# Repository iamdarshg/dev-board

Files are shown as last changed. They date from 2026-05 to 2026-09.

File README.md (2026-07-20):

# dev-real — what's left to do

Self-contained project: board + schematics + libraries. Unzip anywhere and open
`dev-real.kicad_pro` in KiCad 9.

Board is at **0 DRC errors and 0 unconnected items — fully routed.**

---

## 1. Routing complete (historical)

All 14 unconnected items from the previous pass (was 499 originally) have
been resolved, including the last 6 hold-outs around the U13 radar BGA
corner (GND ball M12, an In2/GND stub near (56.9, 16.0), C34 pad 1, U21 pad
26, a split GND plane island on In1, and an NRESET In1↔F gap) — these needed
hand-routing (via-in-pad style connections plus small shoves of a couple of
neighboring nets — FT_RXD, GPIO_4 — that were routed directly under the
affected pads) since the escape-track congestion in that corner defeats the
interactive shove router's default settings. `Inspect → Design Rules
Checker → Run DRC` now reports **0 errors, 0 unconnected** with zones
refilled.

If future edits reintroduce unconnected items, the same workflow applies:

1. Open `dev-real.kicad_pro` → PCB Editor.
2. `Route → Interactive Router Settings…` → set **Mode: Shove** (Walk Around
   struggles near the U13 BGA corner, where several nets route directly
   under neighboring balls).
3. `Inspect → Design Rules Checker → Run DRC`, open the **Unconnected
   Items** tab, double-click an item to zoom to it.
4. Hover the pad → press `X` → route → double-click to finish. Press `V`
   mid-route to drop a via and switch layers.
5. Press `B` to refill all zones before the final DRC check — stale zone
   fill after a track/via edit can itself show up as a false clearance
   violation until refilled.

## 2. Fix SCOPE_BIAS in the schematic

`/AD9609/SCOPE_BIAS` has **no DC reference** anywhere in the schematic — the net
floats on the real board. Open `ad9609bcpzrl7_80_breakout.kicad_sch` and define
the intended bias source, then `Tools → Update PCB from Schematic` (F8).

## 3. Sanity-check before you save

After any edit: press `B` to refill zones, then `Inspect → Design Rules
Checker → Run DRC` and confirm it still reads **0 errors, 0 unconnected**
before `Ctrl+S`.

---

### Design rules already in effect (don't change)

Signal 0.127 mm / vias 0.254 mm with 0.127 mm drill / clearance 0.08 mm /
min through-drill 0.127 mm. Power rails run 0.2–0.5 mm.
The 0.2/0.1 vias on this board are **microvias** — place a new *through*-via
that small and DRC will (correctly) reject it.

### What's in here

- `dev-real.kicad_pcb` — the board
- `dev-real.kicad_pro` — project + design rules (**keep beside the board**;
  without it KiCad invents default rules and DRC becomes meaningless)
- `dev-real.kicad_sch` + 8 hierarchical sheets — full schematic
- `fp-lib-table`, `sym-lib-table` + the custom symbol/footprint libraries they
  reference (AD9609, IWRL6432, MM8108, THS8136, XCC1352, ICM-42670, ENS161,
  MMC5633, plus the project's `.pretty` footprint dirs)

Verified standalone: netlist exports all 318 components across the 9-sheet
hierarchy, and DRC output is identical to the working copy.

Full history, method, DRC report, renders and the routing scripts stay in
`D:\dev-real-updated\dev-real-updated\dev-real-routing-finish\`.

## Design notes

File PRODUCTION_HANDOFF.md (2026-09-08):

# Production handoff

## Release artifacts

- PCB: `dev-real-production.kicad_pcb`
- KiCad project rules: `dev-real-production.kicad_pro`
- Fabrication archive: `dev-real-production-fab.zip`
- DRC report: `dev-real-production-drc.rpt`
- Detailed pair audit: `dev-real-production-length-audit.txt`

The current KiCad 9.0.7 DRC result is **26 warnings, 0 errors, 0 unconnected
items, and 0 footprint errors** after the 2026-09-09 dangling-copper cleanup
and full eight-zone refill. The remaining warnings are explicitly classified
in the current-routing section below.

**Fab outputs are stale as of the L1 change below.** `dev-real-production-fab/`
(gerbers, drill files, `-positions.csv`, `-netlist.xml`, `-drc.rpt`, `.zip`) and
`dev-real-production-length-audit.txt` were generated before L1 was replaced and
rerouted, and were intentionally **not** regenerated here (kicad-cli's default
export job doesn't reproduce this project's curated gerber/drill file set —
e.g. the PTH/NPTH split — without its saved plot-job settings). Before sending
to a fabricator: open `dev-real-production.kicad_pro` in KiCad 9 and re-run
**File → Fabrication Outputs** (or the project's existing plot job) to
regenerate the whole `dev-real-production-fab/` package and `.zip` from the
current board.

## L1 inductor (1 µH buck output, `/Power/SW` → `+3V3`)

L1 was a placeholder (`L_TODO_SELECT_1uH_15Aplus`, physically a 0603 footprint)
and is now **KYOCERA AVX LMLP07C7M1R0DTAS** (1 µH ±20 %, DCR 6.1/6.5 mΩ typ/max,
IDC 15 A typ, Isat 20 A typ) on footprint `L_Kyocera_LMLP07C7D_7.3x6.6mm`
(land pattern built from the LMLP07 series dimensional table in
`datasheets.kyocera-avx.com/LMLPD.pdf` — verify against that drawing before
committing to fab). COUT2 (the buck output cap, itself still a
`C_TODO_SELECT_100uF` placeholder) was nudged ~1.85 mm to make room, and the
~12 local nets crossing the new footprint's footprint were rerouted and
verified against real `kicad-cli pcb drc`.

**Fixed:** the `courtyards_overlap` between C5 and COUT2 noted above has been
resolved. COUT2 could not be moved (the channel between C5 and L1's new body
is too narrow for COUT2's footprint in any orientation, and COUT2's own
routing was already verified/stable), so C5 (100 nF, `C_0603_1608Metric`) was
relocated instead, from (68.5, 59.5) mm to (67.7, 57.75) mm — clear of both
COUT2's and C2's courtyards, with a real `kicad-cli pcb drc` clean pass
(0 violations / 0 unconnected). Its two local stub nets were rerouted to the
new pad positions on the Top Layer: `/Power/RIPPLE_INJ` (pad at
(66.925, 57.75)) reconnects with a single straight segment to its existing
run at (65.674999, 57.449999); `/Power/FB` (pad at (68.475, 57.75)) is
routed around an `/Power/EXTVDD` track that crosses the direct path, via
waypoints (68.6, 58.0) → (70.4, 58.0) → (70.8, 58.4) → (71.0, 58.4) →
(71.6, 59.0) → (71.0, 59.6) → (69.2, 59.6), rejoining the existing FB run at
(69.3, 59.524999). Six duplicate/redundant `/Power/FB` stub segments left
over from earlier routing passes (all at the same old coordinates) were
deduped down to the single new route in the process.

## High-current trace widths

The `/Power/SW` and `+3V3` segments added/touched by the L1 reroute were
widened from their as-routed 0.1–0.2 mm to 0.2–0.4 mm (clearance-checked
per segment, matching this board's existing convention for local
high-current power hops — see the `+3V3`/`/Power/SW` segments elsewhere on
the board already at 0.4 mm). A board-wide sweep of the other plausible
current-carrying nets (`/Power/VIN`, `/Power/SVIN`, `/Power/PVDD`,
`/Power/EXTVDD`, the USB VBUS nets) found them already consistent with this
convention (0.18–0.35 mm), with one exception: `/IWRL6432BD/USB_VBUS` had
~7.8 mm routed at only 0.15 mm across a few inner-layer segments. Five of
those segments have been widened to 0.2–0.3 mm. Two short segments — a
4.64 mm run on Power Layer 2 near (52.7–57.2, 27.1–28.0) and a 3.19 mm run
on Ground Layer 1 near (57.5–59.5, 28.3–30.7) — remain at 0.15 mm because a
neighboring `/Power/1V8` via sits close enough that widening them trips
real DRC clearance; widening those two needs either moving that via or
re-routing around it, left for interactive follow-up.

## ADC/DAC test breakout

The exposed 1.0 mm test pads are grouped on the bottom edge at 2.0 mm pitch:

| Reference | Net | Position (mm) |
|---|---|---:|
| TP8 | ADC VIN+ | 79, 11 |
| TP9 | ADC VIN- | 81, 11 |
| TP1 | DAC red / AR | 83, 11 |
| TP2 | DAC green / AG | 85, 11 |
| TP3 | DAC blue / AB | 87, 11 |

ADC test-branch mismatch is 0.509 mm. These are measurement branches; keep probes and flying leads short.

## Current routing status (2026-09-09; cleaned manual-routing candidate)

The checked-in board contains the latest manual KiCad routing plus a
conservative basic-DRC cleanup. The cleanup removed **59 zero-pad signal track
segments**, **20 zero-pad signal vias**, **5 byte-identical duplicate vias**,
and **12 exact F.SilkS primitives** named by DRC. The undersized `TR1` and `U6`
reference text was resized to 0.8 mm and moved clear. This eliminated every
`silk_over_copper`, `silk_overlap`, and `text_height` violation. A deliberately
broader cleanup was tested and rejected because it created a genuine
unconnected item; sensitive and ambiguous one-pad routes therefore remain for
visual review instead of being deleted automatically.

The 2026-09-09 follow-up then iteratively removed every newly exposed dead-end
chain that passed a fresh connectivity check: **90 additional dangling track
blocks and 27 additional dangling-via blocks** were removed. Nine more
redundant members of co-located via pairs were removed directly; combined with
the dangling-via removal, this cleared **18 of the 20** co-location markers.
All eight zones were refilled. The refill removed the two former physical
via-to-zone conflicts (four error records) without creating shorts or
unconnected items.

KiCad 9.0.7 DRC on the resulting board reports **26 warnings, 0 errors, 0
unconnected items, and 0 footprint errors**. The remaining warnings are:

- **One `track_dangling` marker:** `/STM32H7/JTDI` at approximately
  (21.5420, 40.3517) mm. A test deletion created a real missing connection, so
  that deletion was reverted and this marker is intentionally accepted.
- **Two `holes_co_located` markers:** the `/Power/SW` microvia-to-buried-via
  transitions at (71.5000, 66.0000) mm and (71.5000, 66.2000) mm. Removing a
  member created a missing connection. A tested stagger-and-bridge alternative
  cleared co-location but created four `/Power/SW` to `+3V3` shorts after zone
  refill, so it too was reverted. These are required stacked transitions and
  need fabricator approval rather than deletion.
- **Five `copper_sliver` markers:** two Top Layer, two Bottom Layer, and one
  Power Layer 2. KiCad's machine-readable report supplies no coordinates or
  attached objects for these markers. A complete eight-zone refill was clean
  electrically but did not remove the warnings, so they remain accepted for
  later interactive marker inspection rather than hiding them by lowering DRC
  severity.
- **Ten `hole_to_hole` warnings:** remaining HDI drill-spacing/stack geometry
  that must be accepted by the selected fabricator or manually restacked.
- **Eight `lib_footprint_mismatch` warnings:** `J7`, `U3`, `RANT1`, and
  `CANT1` reflect intentional local silkscreen cleanup; `NT1`, `U21`, `U14`,
  and `U15` were pre-existing. There are no footprint errors.

This remains a review candidate, not a fabrication release. The previously
released board at commit `3a95473` remains the clean fabrication baseline, and
the fabrication outputs listed above have not been regenerated.

The following are the remaining measured end-to-end pair mismatches on the
checked-in board. They are documented for interactive KiCad follow-up; they
must not be treated as solved merely because the board passes ordinary DRC:

| Interface | Measured mismatch | Status |
|---|---:|---|
| IWRL USB DM/DP to J10 | 0.097 mm | manually tuned; verify after DRC fix |
| RP2350 USB D-/D+ to J4 | 0.967 mm | manually tuned; verify after DRC fix |
| STM32 USB FS D-/D+ to J20 | 0.414 mm | manually tuned; verify after DRC fixes |
| AD9609 sample clock CLK-/CLK+ | 0.304 mm | manually tuned; verify after DRC fixes |
| Ethernet RX RX-/RX+ to J21 | 0.021 mm | manually tuned; verify after DRC fix |
| Ethernet TX TX-/TX+ | 0.000 mm | corrected and DRC-verified |
| MM8108 USB D-/D+ to J17 | 0.675 mm | manually tuned; verify after DRC fix |
| AD9609 ADC input | 0.581 mm | open; analog path review |

The IWRL connector is J10 (`USB-C USB2 DEBUG`); the RP2350 connector is J4
(`USB-C Receptacle USB2`). The STM32 USB connector is J20, and the MM8108
USB connector is J17. The current edited-board values above supersede the
older clean-board values in the historical audit below. The basic cleanup was
limited to zero-pad islands, exact duplicates, and silkscreen; it did not
intentionally tune these endpoint paths. They are not release values until DRC
is clean again.

The first-order field-based impedance estimate used the checked-in four-layer
stackup (1.6 mm nominal, 175 um prepreg to the adjacent reference plane,
FR-4 dielectric approximately 4.4) and the actual routed widths. It estimates
roughly 65--70 ohm single-ended and 89--96 ohm differential for the common
0.127--0.300 mm geometries. This is an engineering estimate, not a fab
acceptance measurement: the fabricator must field-solve the final stackup,
copper thickness, soldermask, and trace spacing and provide a coupon or
controlled-impedance confirmation. The short CC1352 RF balanced launches are
length-matched, but their 50 ohm launch impedance has not been certified by a
3-D field solver.

## Historical clean-board pair-length audit

Key routed mismatches:

| Pair | End-to-end mismatch |
|---|---:|
| ADC analog input | 0.072 mm |
| ADC sample clock | 0.572 mm |
| Ethernet RX | 0.260 mm |
| Ethernet TX | 3.723 mm |
| STM32 USB FS | 5.049 mm |
| MM8108 USB | 7.819 mm |
| RP2350 USB | 9.702 mm |
| FTDI USB | 16.235 mm |

The dense USB routes were not given forced serpentine sections because no collision-free tuning corridor was available. The STM32, RP2350, and FTDI paths are identified as full-speed USB in this design and are retained as routed. Confirm the MM8108 interface speed before fabrication: if it operates at USB high speed, its 7.819 mm residual mismatch should be rerouted against the module's timing requirement.

The historical Ethernet TX value in the table above predates the committed
correction. Use the 0.000 mm value in the current-routing section for the
checked-in production board.

## Fabricator instructions

- Four copper layers, nominal finished thickness 1.6 mm.
- The board contains F.Cu-to-In1.Cu laser microvias and In1.Cu-to-In2.Cu buried vias. Use an HDI process capable of the separated drill sets supplied in the archive.
- Confirm the smallest finished drill, annular ring, stacked-via policy, via filling/capping, soldermask expansion, and copper-to-edge limits against the KiCad board before accepting the order.
- Differential impedance must be field-solved by the selected fabricator using its actual laminate and plating data. Do not treat the nominal KiCad geometry as an impedance coupon.
- The project says only `Lead-Free` for copper finish; select the required finish explicitly on the fabrication purchase order.

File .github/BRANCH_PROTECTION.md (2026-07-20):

# Protecting the `main` branch

The `KiCad checks` workflow (`.github/workflows/kicad-checks.yml`) runs the KiCad 9
CLI on every pull request into `main` and fails if the production board
(`dev-real-production.kicad_pcb`) is not DRC-clean (0 violations, 0 unconnected).

CI only *reports* status. To actually **block merges** when it fails, `main` must
require that check. GitHub branch-protection settings are not part of the repo
files, so apply one of the following once (repo admin required).

## Required status check context
Use the job's display name exactly:

```
DRC — dev-real-production (required)
```

## Option A — GitHub UI
Settings → Branches → Add branch ruleset (or "Add rule") for `main`:
- Require a pull request before merging (≥ 1 approval recommended).
- Require status checks to pass before merging → add **DRC — dev-real-production (required)**.
- Require branches to be up to date before merging.
- Do not allow force pushes; do not allow deletions.

## Option B — `gh` CLI (REST)
```sh
gh api -X PUT repos/iamdarshg/dev-board/branches/main/protection \
  -H "Accept: application/vnd.github+json" \
  -f 'required_status_checks[strict]=true' \
  -f 'required_status_checks[contexts][]=DRC — dev-real-production (required)' \
  -f 'enforce_admins=true' \
  -f 'required_pull_request_reviews[required_approving_review_count]=1' \
  -f 'restrictions=' \
  -F 'allow_force_pushes=false' \
  -F 'allow_deletions=false'
```
(`restrictions` must be sent as null; with `gh api` an empty `-f 'restrictions='`
sends null. If your `gh` version rejects it, use the raw curl form below.)

## Option C — raw REST (curl)
```sh
curl -X PUT \
  -H "Authorization: Bearer $GITHUB_TOKEN" \
  -H "Accept: application/vnd.github+json" \
  https://api.github.com/repos/iamdarshg/dev-board/branches/main/protection \
  -d '{
    "required_status_checks": {
      "strict": true,
      "contexts": ["DRC — dev-real-production (required)"]
    },
    "enforce_admins": true,
    "required_pull_request_reviews": { "required_approving_review_count": 1 },
    "restrictions": null,
    "allow_force_pushes": false,
    "allow_deletions": false
  }'
```

Once the check has run at least once on a PR, its context becomes selectable in the
UI. After enabling, a PR that breaks production DRC cannot be merged into `main`.

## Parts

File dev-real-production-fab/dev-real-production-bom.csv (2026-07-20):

Refs | Value | Footprint | Qty | DNP
C1 | 4.7uF / >=10V | Capacitor_SMD:C_0805_2012Metric | 1
C2 | 2.2uF / >=10V | Capacitor_SMD:C_0603_1608Metric | 1
C3,C5,C65,C69,C70,C75,C98,C99,C102,C106,C107,C109,C110,C112-C116,C119-C126,C129,C130,C134 | 100nF | Capacitor_SMD:C_0603_1608Metric | 29
C4,C135 | 4.7nF | Capacitor_SMD:C_0603_1608Metric | 2
C6,C7 | 15pF C0G | RP2350B_minimal_hier:C_0402_1005Metric | 2
C8-C10 | 4.7uF 6.3V X5R | RP2350B_minimal_hier:C_0402_1005Metric | 3
C11,C12,C14,C16,C17,C20,C34,C35,C45 | 0.1uF | Capacitor_SMD:C_0402_1005Metric | 9
C13,C15,C18 | 22uF | Capacitor_SMD:C_0603_1608Metric | 3
C19,C26,C27,C37,C40,C49,C54,C61 | 1uF | Capacitor_SMD:C_0402_1005Metric | 8
C21-C23 | 100pF | Capacitor_SMD:C_0201_0603Metric | 3
C24,C25 | 4.7pF | Capacitor_SMD:C_0402_1005Metric | 2
C28,C39 | 0.22uF | Capacitor_SMD:C_0402_1005Metric | 2
C29,C30 | 22pF | Capacitor_SMD:C_0402_1005Metric | 2
C31,C33,C41-C43 | 2.2uF | Capacitor_SMD:C_0402_1005Metric | 5
C32 | 0.047uF | Capacitor_SMD:C_0402_1005Metric | 1
C36,C38,C44,C46,C47 | 10uF | Capacitor_SMD:C_0402_1005Metric | 5
C48 | 4.7uF | Capacitor_SMD:C_0402_1005Metric | 1
C50,C52,C53,C60,C71,C76,C77,C83 | 10uF | Capacitor_SMD:C_0603_1608Metric | 8
C51,C55-C59,C62,C63 | 100nF | Capacitor_SMD:C_0402_1005Metric | 8
C64,C67,C74 | 10uF | Capacitor_SMD:C_0805_2012Metric | 3
C66 | 22uF | Capacitor_SMD:C_0805_2012Metric | 1
C68,C78,C84,C89,C103,C118,C131,C132 | 1uF | Capacitor_SMD:C_0603_1608Metric | 8
C72,C79,C81,C85-C88,C92,C93 | 100n | Capacitor_SMD:C_0603_1608Metric | 9
C73 | 100nF BIAS | Capacitor_SMD:C_0603_1608Metric | 1
C80 | 100nF AVDD | Capacitor_SMD:C_0603_1608Metric | 1
C82 | 100nF DVDD | Capacitor_SMD:C_0603_1608Metric | 1
C90 | 100nF VDD | Capacitor_SMD:C_0603_1608Metric | 1
C91 | 100nF VOCM | Capacitor_SMD:C_0603_1608Metric | 1
C94 | 1nF VDD HF | Capacitor_SMD:C_0402_1005Metric | 1
C95 | 22pF C0G | Capacitor_SMD:C_0402_1005Metric | 1
C96,C101 | 12pF | Capacitor_SMD:C_0603_1608Metric | 2
C97,C105,C111 | 2.2uF low-ESR | Capacitor_SMD:C_0603_1608Metric | 3
C100,C104 | 4.7uF | Capacitor_SMD:C_0603_1608Metric | 2
C108,C117 | 6.8pF | Capacitor_SMD:C_0603_1608Metric | 2
C127,C128 | 18pF | Capacitor_SMD:C_0603_1608Metric | 2
C133 | 2.2uF | Capacitor_SMD:C_0603_1608Metric | 1
CIN1 | 10uF / >=10V | Capacitor_SMD:C_1210_3225Metric | 1
CIN2 | 39uF / >=10V | Capacitor_SMD:C_1210_3225Metric | 1
COUT1 | 47uF / >=6.3V | Capacitor_SMD:C_1210_3225Metric | 1
COUT2 | 100uF / >=6.3V | Capacitor_SMD:C_TODO_SELECT_100uF | 1
CSS1 | 12nF | Capacitor_SMD:C_0603_1608Metric | 1
CSVIN1 | 1uF / >=10V | Capacitor_SMD:C_0805_2012Metric | 1
C_ADC1,C_DVDD1-C_DVDD3,C_IOVDD1-C_IOVDD8,C_QSPI1,C_USB1,C_USB2,C_USBOTP1 | 100nF | RP2350B_minimal_hier:C_0402_1005Metric | 16
C_IOBULK1 | 10uF | RP2350B_minimal_hier:C_0402_1005Metric | 1
FB1,FB2,FB4-FB6 | 600R@100MHz | Inductor_SMD:L_0603_1608Metric | 5
FB3 | 600R@100MHz | Inductor_SMD:L_0805_2012Metric | 1
FB7-FB9 | 600R@100MHz | Inductor_SMD:L_0603_1608Metric_Pad0.95x0.95mm_HandSolder | 3
IC1 | ICM-42670-P | ICM-42670-P:ICM42670P | 1
IC2 | ENS161-BLGT_LGA9_T&R_1k5 | ENS161-BLGT_LGA9_T&R_1k5:ENS161BLGTLGA9TR1k5 | 1
J1 | VIN_IN | TerminalBlock_Phoenix:TerminalBlock_Phoenix_MKDS-1,5-2_1x02_P5.00mm_Horizontal | 1
J2 | TP_EN_PG | TerminalBlock_Phoenix:TerminalBlock_Phoenix_MKDS-1,5-2_1x02_P5.00mm_Horizontal | 1
J3 | TP_SW_FB | TerminalBlock_Phoenix:TerminalBlock_Phoenix_MKDS-1,5-2_1x02_P5.00mm_Horizontal | 1
J4,J17 | USB-C Receptacle USB2 | Connector_USB:USB_C_Receptacle_GCT_USB4105-xx-A_16P_TopMnt_Horizontal | 2
J5 | Conn_01x03_Pin | Connector_PinSocket_2.54mm:PinSocket_1x03_P2.54mm_Vertical | 1
J6 | ARM_Cortex_Debug_10 | Connector_PinHeader_1.27mm:PinHeader_2x05_P1.27mm_Vertical | 1
J7 | SMA_ANT_50OHM | Connector_Coaxial:SMA_Molex_73251-2120_EdgeMount_Horizontal | 1
J8 | 3V3_IN | Connector_PinHeader_2.54mm:PinHeader_1x02_P2.54mm_Vertical | 1
J10 | USB-C USB2 DEBUG | Connector_USB:USB_C_Receptacle_GCT_USB4105-xx-A_16P_TopMnt_Horizontal | 1
J11,J16 | ARM_JTAG_10 | Connector_PinHeader_1.27mm:PinHeader_2x05_P1.27mm_Vertical | 2
J12 | SOP0_SELECT | Connector_PinHeader_2.54mm:PinHeader_1x03_P2.54mm_Vertical | 1
J13 | SOP1_SELECT | Connector_PinHeader_2.54mm:PinHeader_1x03_P2.54mm_Vertical | 1
J14,J15 | Conn_01x03 | Connector_PinHeader_2.54mm:PinHeader_1x03_P2.54mm_Vertical | 2
J18 | Conn_01x03_Pin | Connector_PinHeader_2.54mm:PinHeader_1x03_P2.54mm_Vertical | 1
J19 | Cortex SWD/JTAG | Connector_PinHeader_1.27mm:PinHeader_2x05_P1.27mm_Vertical | 1
J20 | USB-C USB2 DEVICE | Connector_USB:USB_C_Receptacle_GCT_USB4105-xx-A_16P_TopMnt_Horizontal | 1
J21 | HR911105A MAGJACK | Connector_RJ:RJ45_Hanrun_HR911105A | 1
J22 | Conn_02x10_Counter_Clockwise | Connector_PinHeader_2.54mm:PinHeader_2x10_P2.54mm_Vertical | 1
J23 | Conn_02x04_Odd_Even | Connector_PinHeader_2.54mm:PinHeader_2x04_P2.54mm_Vertical | 1
L1 | 1uH LMLP07C7M1R0DTAS, Idc 15A / Isat 20A | Inductor_SMD:L_Kyocera_LMLP07C7D_7.3x6.6mm | 1
L2 | 3.3uH Abracon AOTA-B201610S3R3-101-T | RP2350B_minimal_hier:L_Abracon_AOTA-B201610S_2.0x1.6mm | 1
NT1 | AGND_to_PGND_single_point | NetTie:NetTie-2_SMD_Pad0.5mm | 1
R1,R35,R43,R46-R49,R62,REN1 | 100k | Resistor_SMD:R_0603_1608Metric | 9
R2 | 60.4k | Resistor_SMD:R_0603_1608Metric | 1
R3,R4 | 2R | Resistor_SMD:R_0603_1608Metric | 2
R5 | 24.3k | Resistor_SMD:R_0603_1608Metric | 1
R6,R70,R71 | 1k | RP2350B_minimal_hier:R_0402_1005Metric | 3
R7,R8,R28,R29 | 27R | RP2350B_minimal_hier:R_0402_1005Metric | 4
R9 | 33R 1% | RP2350B_minimal_hier:R_0402_1005Metric | 1
R10 | 100k | Resistor_SMD:R_0402_1005Metric | 1
R11,R12 | 10k | Resistor_SMD:R_0402_1005Metric | 2
R13,R14 | 27 | Resistor_SMD:R_0402_1005Metric | 2
R15,R16 | 0 | Resistor_SMD:R_0402_1005Metric | 2
R17 | 47.5k | Resistor_SMD:R_0402_1005Metric | 1
R18,R19 | 2M | Resistor_SMD:R_0402_1005Metric | 2
R20-R22 | 75R | Resistor_SMD:R_0402_1005Metric | 3
R23-R25,R27 | 2.2k | Resistor_SMD:R_0603_1608Metric | 4
R26 | 3.8k | Resistor_SMD:R_0402_1005Metric | 1
R30-R34 | 47k | Resistor_SMD:R_0603_1608Metric | 5
R36,R37,R39,R40 | 1k 0.1% | Resistor_SMD:R_0402_1005Metric | 4
R38 | 10k 1% | Resistor_SMD:R_0603_1608Metric | 1
R41,R42 | 33R | Resistor_SMD:R_0402_1005Metric | 2
R44,R50 | 0R | Resistor_SMD:R_0603_1608Metric | 2
R45,R65 | 1M | Resistor_SMD:R_0603_1608Metric | 2
R51-R55,R57,RPG1 | 10k | Resistor_SMD:R_0603_1608Metric | 7
R56 | 1.5k | Resistor_SMD:R_0603_1608Metric | 1
R58,R59 | 22R | Resistor_SMD:R_0603_1608Metric | 2
R60 | 100R | Resistor_SMD:R_0603_1608Metric | 1
R61 | 12.1k 1% | Resistor_SMD:R_0603_1608Metric | 1
R63,R64 | 5.1k | Resistor_SMD:R_0603_1608Metric | 2
R66,R67 | 330R | Resistor_SMD:R_0603_1608Metric | 2
R68,R69 | 10k STRAP LOW | Resistor_SMD:R_0603_1608Metric | 2
RANT1 | 0R | Resistor_SMD:R_0402_1005Metric | 1
RBOT1 | 665R | Resistor_SMD:R_0603_1608Metric | 1
RCC1-RCC4 | 5.1k | RP2350B_minimal_hier:R_0402_1005Metric | 4
RCL1 | 2.21k | Resistor_SMD:R_0603_1608Metric | 1
RTOP1 | 3.00k | Resistor_SMD:R_0603_1608Metric | 1
TP1 | AR_TP | TestPoint:TestPoint_Pad_D1.0mm | 1
TP2 | AG_TP | TestPoint:TestPoint_Pad_D1.0mm | 1
TP3 | AB_TP | TestPoint:TestPoint_Pad_D1.0mm | 1
TP4,TP5 | VCM | TestPoint:TestPoint_Pad_D1.0mm | 2
TP6 | VREF | TestPoint:TestPoint_Pad_D1.0mm | 1
TP7 | AVDD_1V8 | TestPoint:TestPoint_Pad_D1.0mm | 1
TP8 | ADC_VIN_P | TestPoint:TestPoint_Pad_D1.0mm | 1
TP9 | ADC_VIN_N | TestPoint:TestPoint_Pad_D1.0mm | 1
TR1 | 0900PC15A0036 | XCC1352R1F3RGZR_RF:Johanson_0900PC15A0036_0805_10Pin | 1
U1 | MMC5633NJL | Package_BGA:WLP-4_0.86x0.86mm_P0.4mm | 1
U2 | LPS22HH | Package_LGA:ST_HLGA-10_2x2mm_P0.5mm_LayoutBorder3x2y | 1
U3 | MIC28516T-E/PHA | MIC28516:MIC28516-VQFN-32-6x6mm-P0.65-MultipleEP | 1
U4 | RP2350B | RP2350B_minimal_hier:RP2350B_QFN80_10x10mm_P0.4mm_EP | 1
U5 | XCC1352R1F3RGZR | Package_DFN_QFN:VQFN-48-1EP_7x7mm_P0.5mm_EP5.15x5.15mm | 1
U6 | XMSSJJ3G0PA-054 | XCC1352R1F3RGZR_RF:Murata_XMSSJJ3G0PA-054 | 1
U7 | TLV75518PDBV | Package_TO_SOT_SMD:SOT-23-5 | 1
U8 | TLV75518PDBVR | Package_TO_SOT_SMD:SOT-23-5 | 1
U9,U10 | USBLC6-2P6 | Package_TO_SOT_SMD:SOT-666 | 2
U11,U12 | FT230XS-R | Package_SO:SSOP-16_3.9x4.9mm_P0.635mm | 2
U13 | IWRL6432BDBAAMFR | iwrl6432_custom:IWRL6432_AMF_FCCSP-102_6.45x6.45mm_P0.50mm | 1
U14,U15 | MX25R1635FZUIH0 | Package_SON:WSON-8-1EP_6x5mm_P1.27mm_EP3.4x4mm | 2
U16 | AMS1117-1.8 | Package_TO_SOT_SMD:SOT-223-3_TabPin2 | 1
U17 | THS8136 | THS8136IPHPR:QFP50P900X900X120-49N | 1
U18 | MM8108-MF15457 | MM8108-MF15457:MM8108MF15457 | 1
U19 | AP2112K-1.8 | Package_TO_SOT_SMD:SOT-23-5 | 1
U20 | PGA113AIDGSR | Package_SO:VSSOP-10_3x3mm_P0.5mm | 1
U21 | AD9609BCPZRL7-80 | Package_DFN_QFN:QFN-32-1EP_5x5mm_P0.5mm_EP3.45x3.45mm_ThermalVias | 1
U22 | MCP6D11T-E/MS | Package_SO:MSOP-8_3x3mm_P0.65mm | 1
U23 | STM32H7S3Z8T6 | Package_QFP:LQFP-144_20x20mm_P0.5mm | 1
U24 | LAN8742A-CZ-TR | Package_DFN_QFN:QFN-24-1EP_4x4mm_P0.5mm_EP2.6x2.6mm | 1
U25 | USBLC6-2SC6 | Package_TO_SOT_SMD:SOT-23-6 | 1
Y1 | 12MHz ABM8-272-T3 | RP2350B_minimal_hier:Crystal_ABM8_3.2x2.5mm | 1
Y2 | 48MHz | Crystal:Crystal_SMD_3225-2Pin_3.2x2.5mm | 1
Y3 | 40MHz | Crystal:Crystal_SMD_3225-2Pin_3.2x2.5mm | 1
Y4 | 40MHz | Crystal:Crystal_SMD_3225-4Pin_3.2x2.5mm | 1
Y5 | 24MHz | Crystal:Crystal_SMD_3225-4Pin_3.2x2.5mm | 1
Y6 | 32.768kHz | Crystal:Crystal_SMD_3215-2Pin_3.2x1.5mm | 1
Y7 | 25MHz | Crystal:Crystal_SMD_3225-4Pin_3.2x2.5mm | 1

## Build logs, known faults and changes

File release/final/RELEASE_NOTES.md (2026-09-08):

# dev-board Fabrication Release Notes

Revision: main @ (see SHA256SUMS.csv for exact source hashes)
Generated: 2026-09-08 (Asia/Calcutta)
Generator: KiCad 9.0.7 CLI

## Contents

- dev-real-gerbers/ — Gerbers (F.Cu, In1, In2, B.Cu, masks, pastes, silkscreens, Edge.Cuts) + Excellon drills (PTH + 3 blind/buried lamination pairs) + drill maps (PDF) for dev-real.kicad_pcb
- dev-real-production-gerbers/ — Same set for dev-real-production.kicad_pcb
- dev-real-bom.csv / dev-real-production-bom.csv — Bill of Materials
- dev-real-positions.csv / dev-real-production-positions.csv — Pick-and-place positions
- dev-real-schematic.pdf — Full hierarchical schematic (9 sheets)
- erc-report.rpt — Full-hierarchy ERC report
- drc-dev-real.rpt / drc-dev-real-production.rpt — DRC reports with schematic parity

## Verification results

| Check | dev-real | dev-real-production |
|---|---|---|
| DRC errors | 0 | 0 |
| DRC unconnected items | 0 | 0 |
| ERC errors | 88 | (same schematic) |
| ERC warnings | 840 | (same schematic) |
| Board size | 105 x 105 mm | 105 x 105 mm |
| Layers | 4 (F.Cu/In1-GND/In2-PWR/B.Cu), 1.6 mm | same |

ERC error classification: all remaining ERC errors are deliberate design conditions or
library-symbol consistency warnings — no actual electrical faults found:
- power_pin_not_driven (32): power-input pins driven through hierarchical sheet boundaries;
  KiCad''s ERC cannot see the driving source across sheets.
- label_dangling (25): root-sheet hierarchical labels for optional/debug interfaces left unwired by design.
- pin_not_connected (7): deliberately unused RESV/NC pins on IC1, J6 pin 7, U5 DIO_7.
- hier_label_mismatch (9): hierarchical labels present in child sheets but intentionally not broken out to parent.
- pin_to_pin (1): VDDA_10RF output-output tie on U13 (IWRL6432) per TI reference design.

## Known accepted issue: /AD9609/SCOPE_BIAS

The net /AD9609/SCOPE_BIAS connects only R36 pin 2 and C73 pin 2 (C73''s other side is GND).
R36''s other end ties to the MCP6D11 differential driver''s IN- summing node. The net has no DC source —
it is electrically floating on the assembled board. Determining the intended bias voltage (GND vs VCM vs VREF,
given the PGA113 output operating point and VOCM setting) would require inventing analogue design intent that
is not documented anywhere in the project. Per explicit user decision this issue is accepted as-is and left
unresolved. It affects only the AD9609 scope-driver subcircuit (U22 MCP6D11 input bias reference).

No other nets are unresolved. Both PCB variants have identical SCOPE_BIAS connectivity (2 pads each).

## Current routing and signal-integrity status

The checked-in production board is the board at commit `3a95473`. After the
Ethernet TX correction, KiCad 9.0.7 DRC reports **0 errors** and **0
unconnected items**. The `/STM32H7/PHY_TXP` and `/STM32H7/PHY_TXN` pair is
length-matched to **0.000 mm**.

Measured end-to-end mismatches still open for interactive KiCad tuning are:

| Interface | Mismatch |
|---|---:|
| IWRL USB DM/DP | 21.981 mm |
| RP2350 USB D-/D+ | 5.925 mm |
| STM32 USB FS D-/D+ | 2.196 mm |
| AD9609 sample clock CLK-/CLK+ | 2.100 mm |

These are not DRC errors. The dense USB/radar corridors need visual review and
length tuning with serpentine sections only where clearance and return-path
continuity remain intact. The first-order field-based estimate for the
checked-in four-layer stackup is approximately 65--70 ohm single-ended and
89--96 ohm differential for the common routed widths. It is an estimate, not
a controlled-impedance release: the selected fabricator must field-solve the
actual laminate/plating/soldermask stackup and confirm the target geometry
with a coupon or equivalent measurement. The CC1352 RF launches are
length-matched, but no 3-D field-solver certification has been performed.

The release is therefore electrically DRC-clean and fabrication-packaged,
with Ethernet TX corrected, but it is not claiming completed impedance
certification or completion of the remaining manual skew-tuning work.

## Manufacturing notes

- HDI build: microvias and blind/buried via pairs (front-In1, front-In2, In1-In2 laminations) require
  sequential-lamination capability; not a standard low-cost through-via process.
- Design rules: min track 0.127 mm, min via 0.254 mm/0.127 drill, microvia 0.2 mm/0.1 drill, clearance 0.08 mm.
- Drill files use absolute origin, millimetre units, Excellon format. Layer-specific drill files are provided
  for the blind/buried pairs plus a combined PTH file.
- Board outline: closed rectangle, Edge.Cuts layer, 105 x 105 mm.
- Zones refilled at time of export; filled polygons present on both boards.

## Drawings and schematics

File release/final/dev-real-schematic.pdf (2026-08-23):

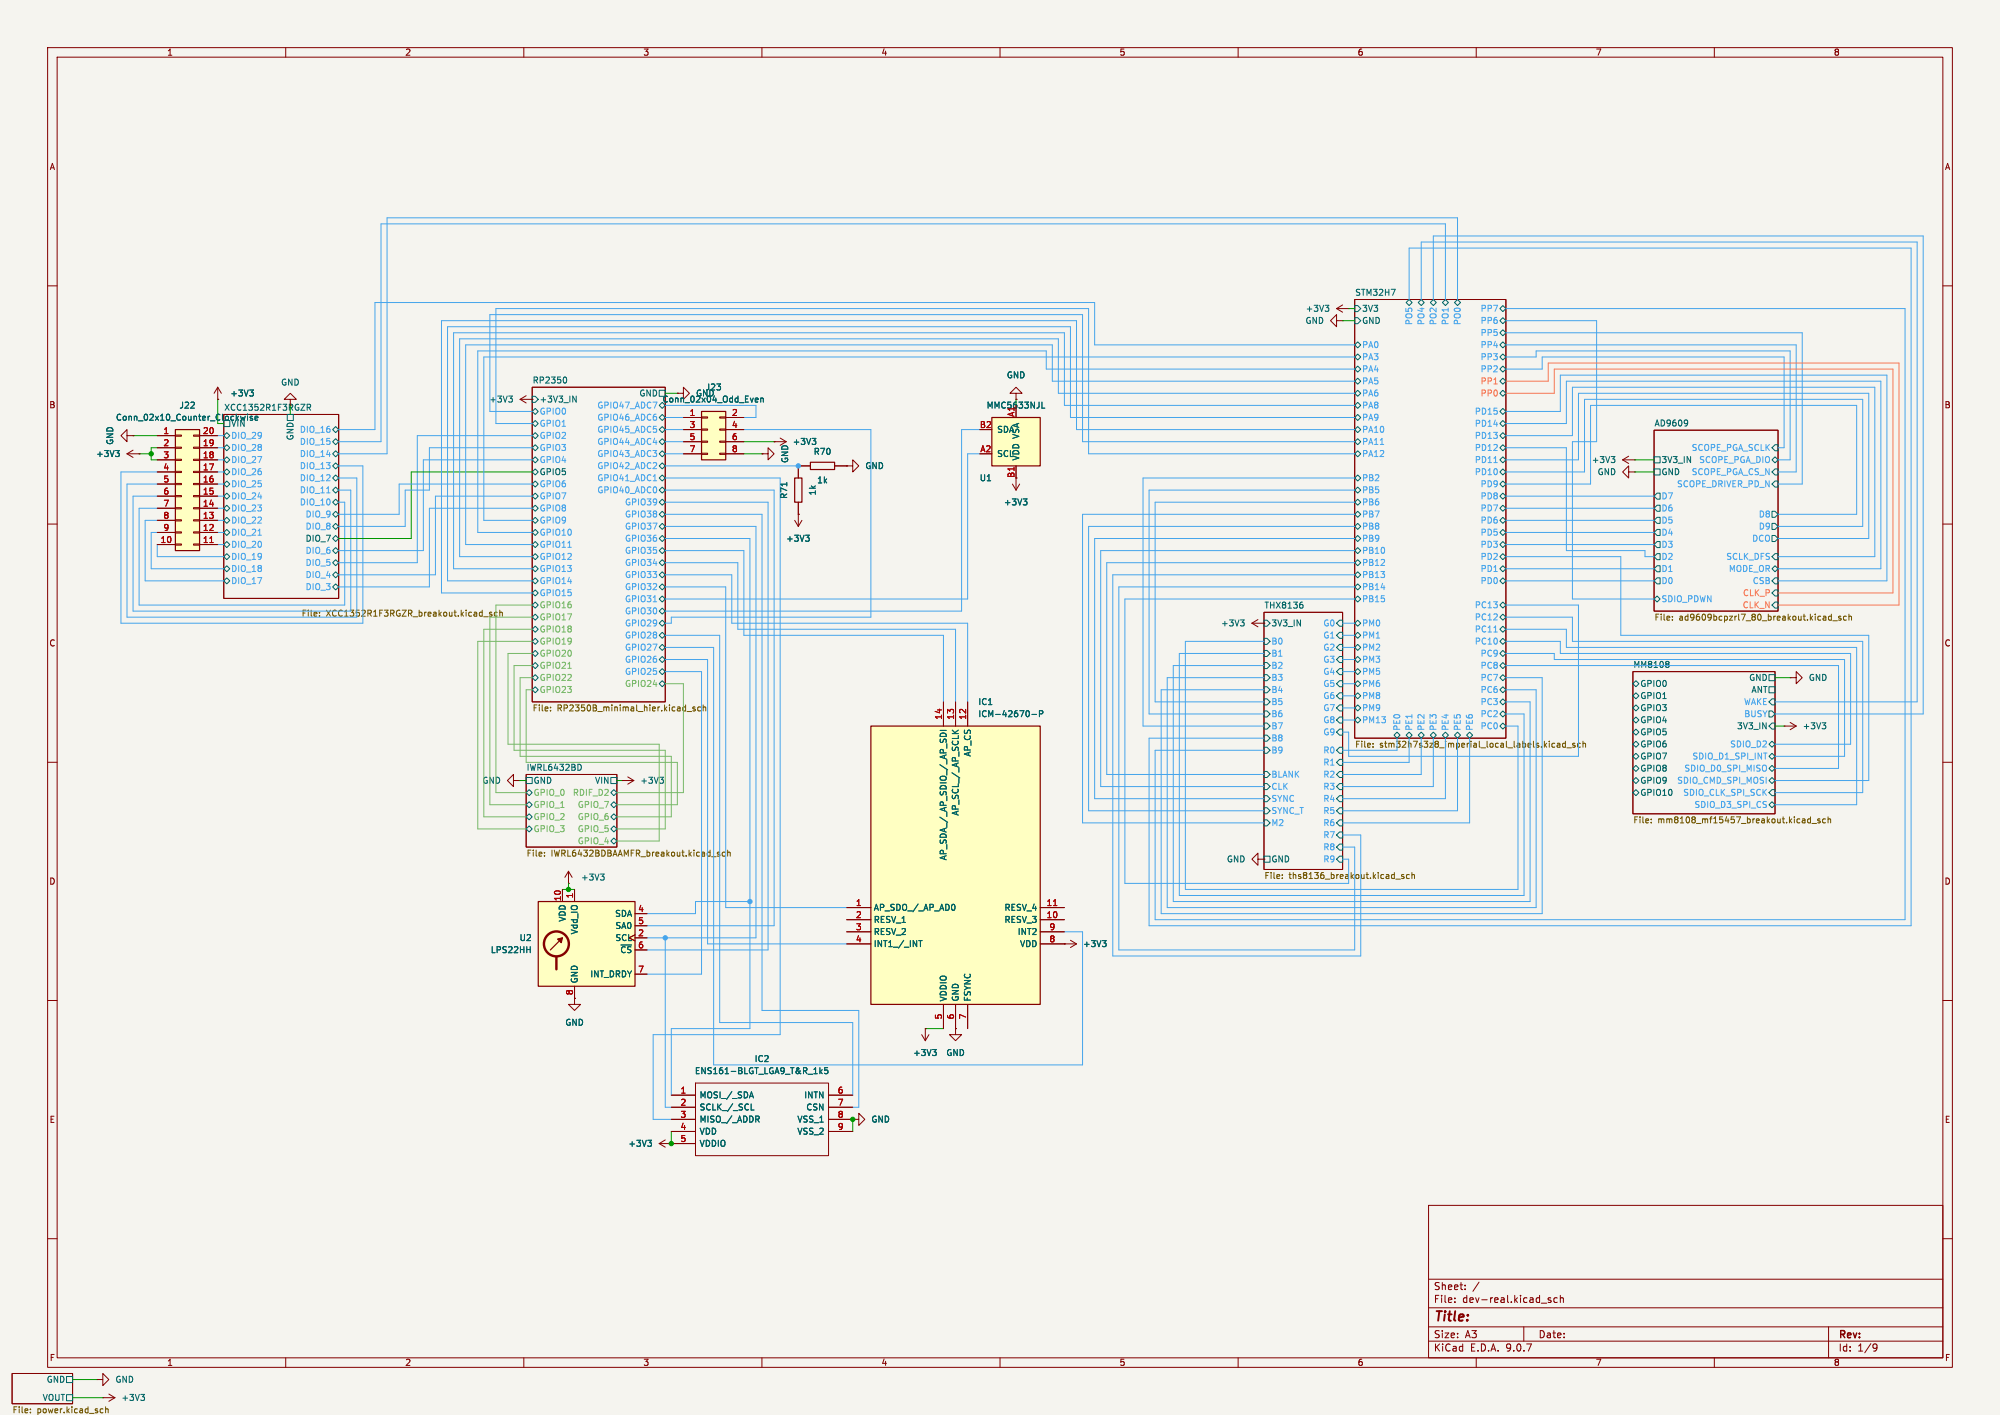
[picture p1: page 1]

Id: 1/9 Title: File: dev-real.kicad_sch Sheet: /

VOUT Power File: power.kicad_sch

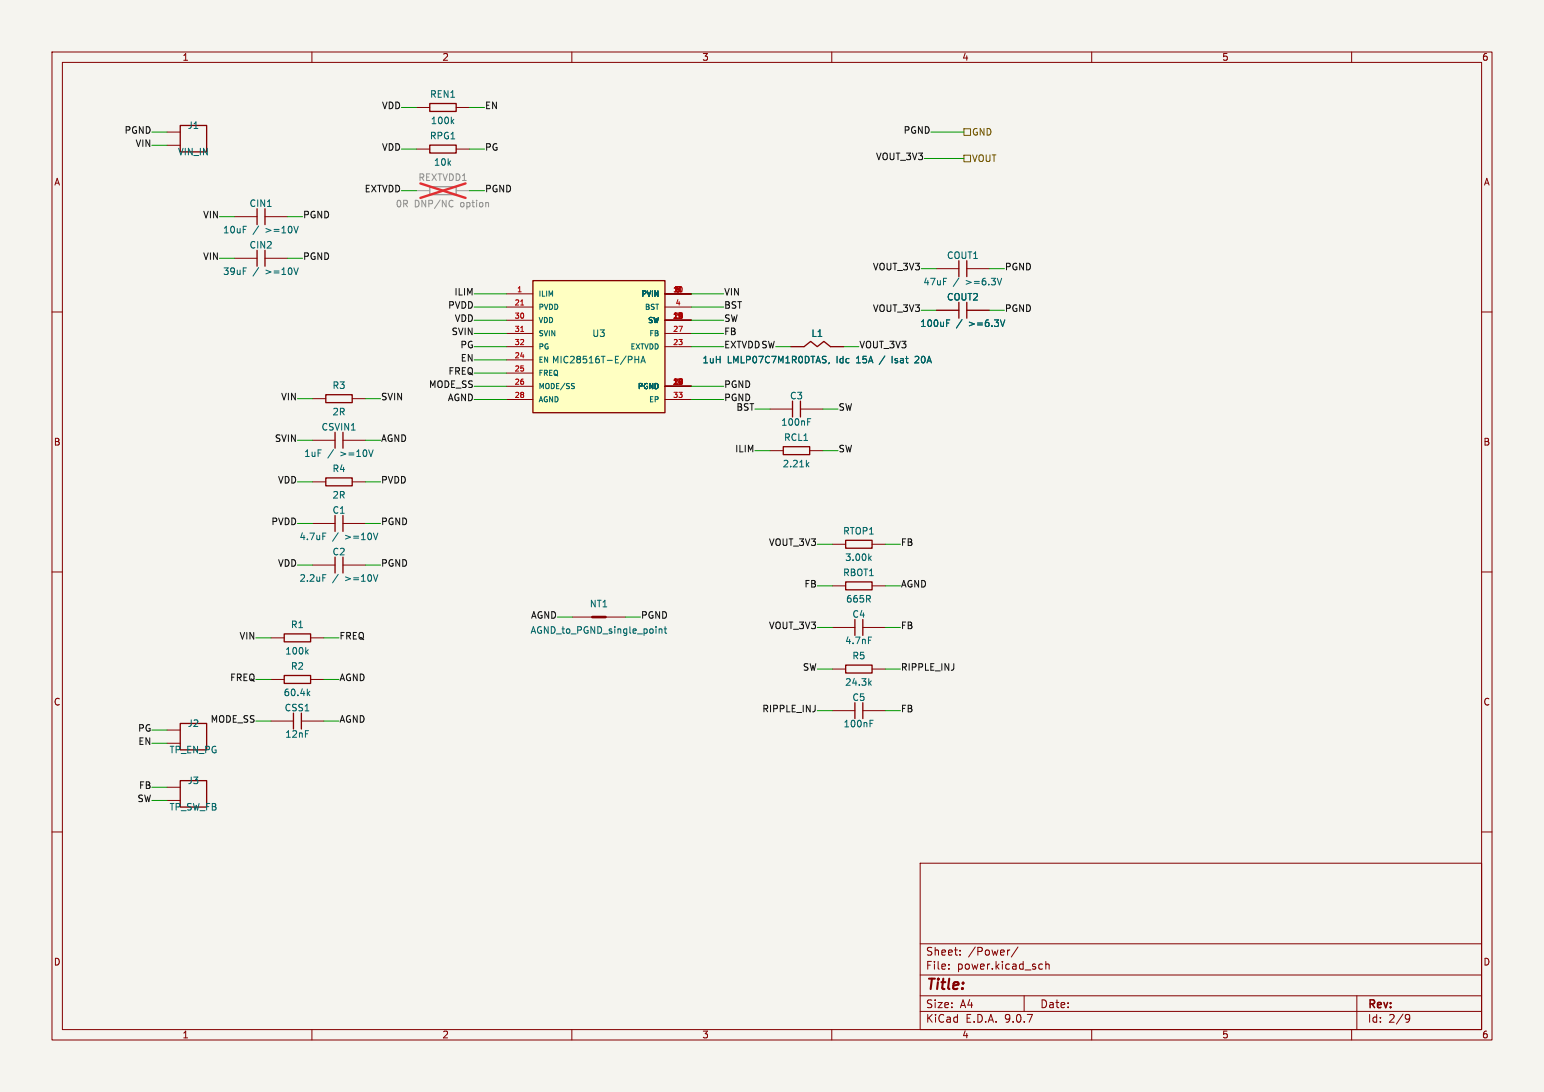
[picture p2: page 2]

Id: 2/9 Title: File: power.kicad_sch Sheet: /Power/

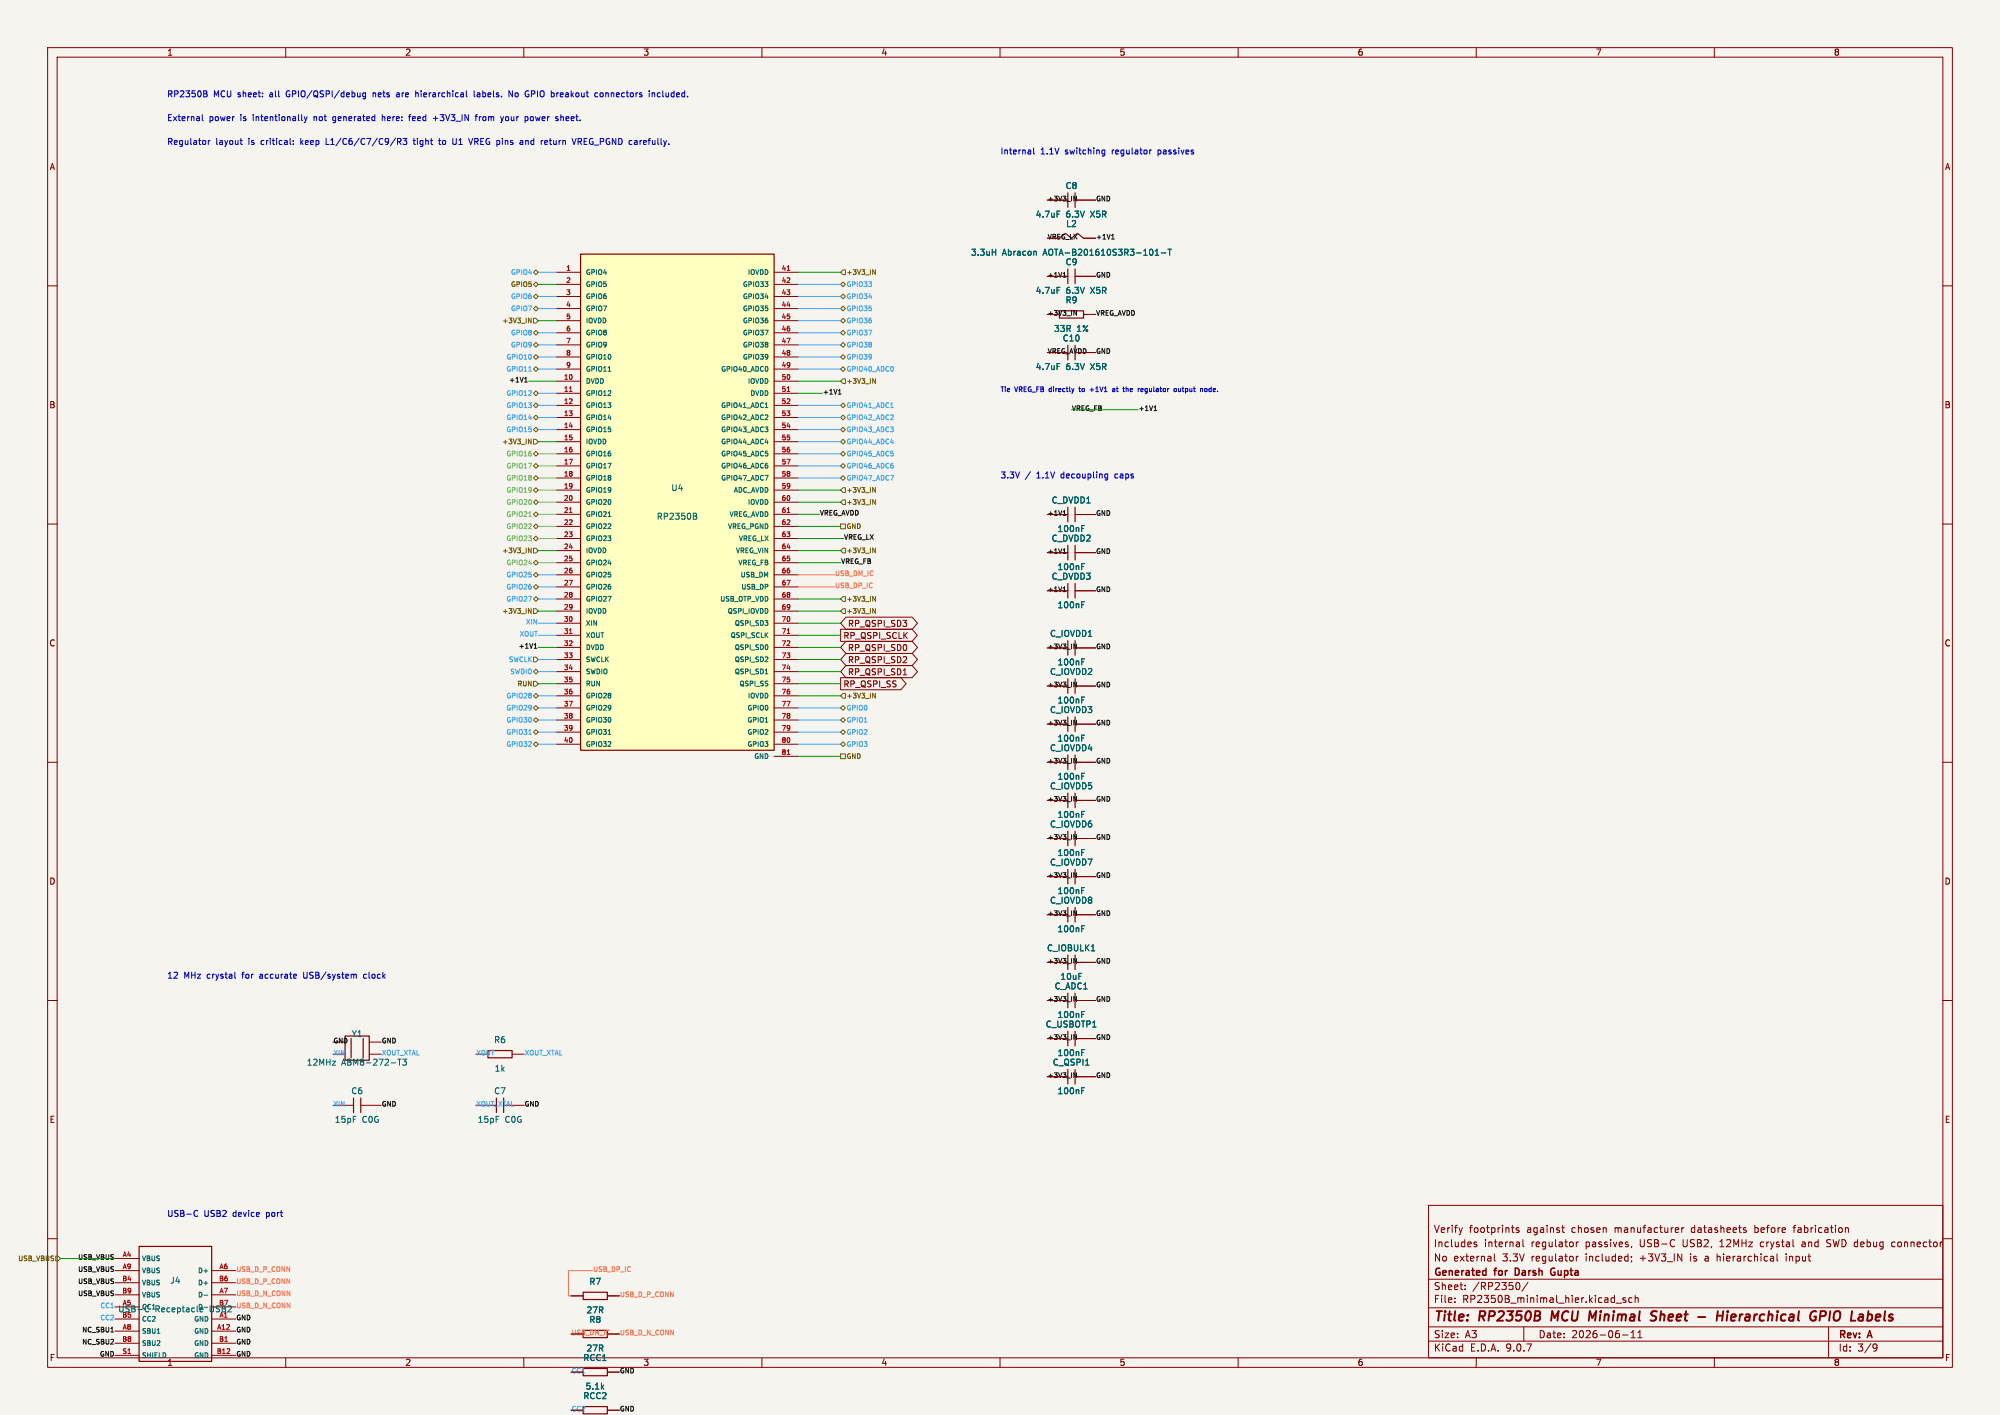
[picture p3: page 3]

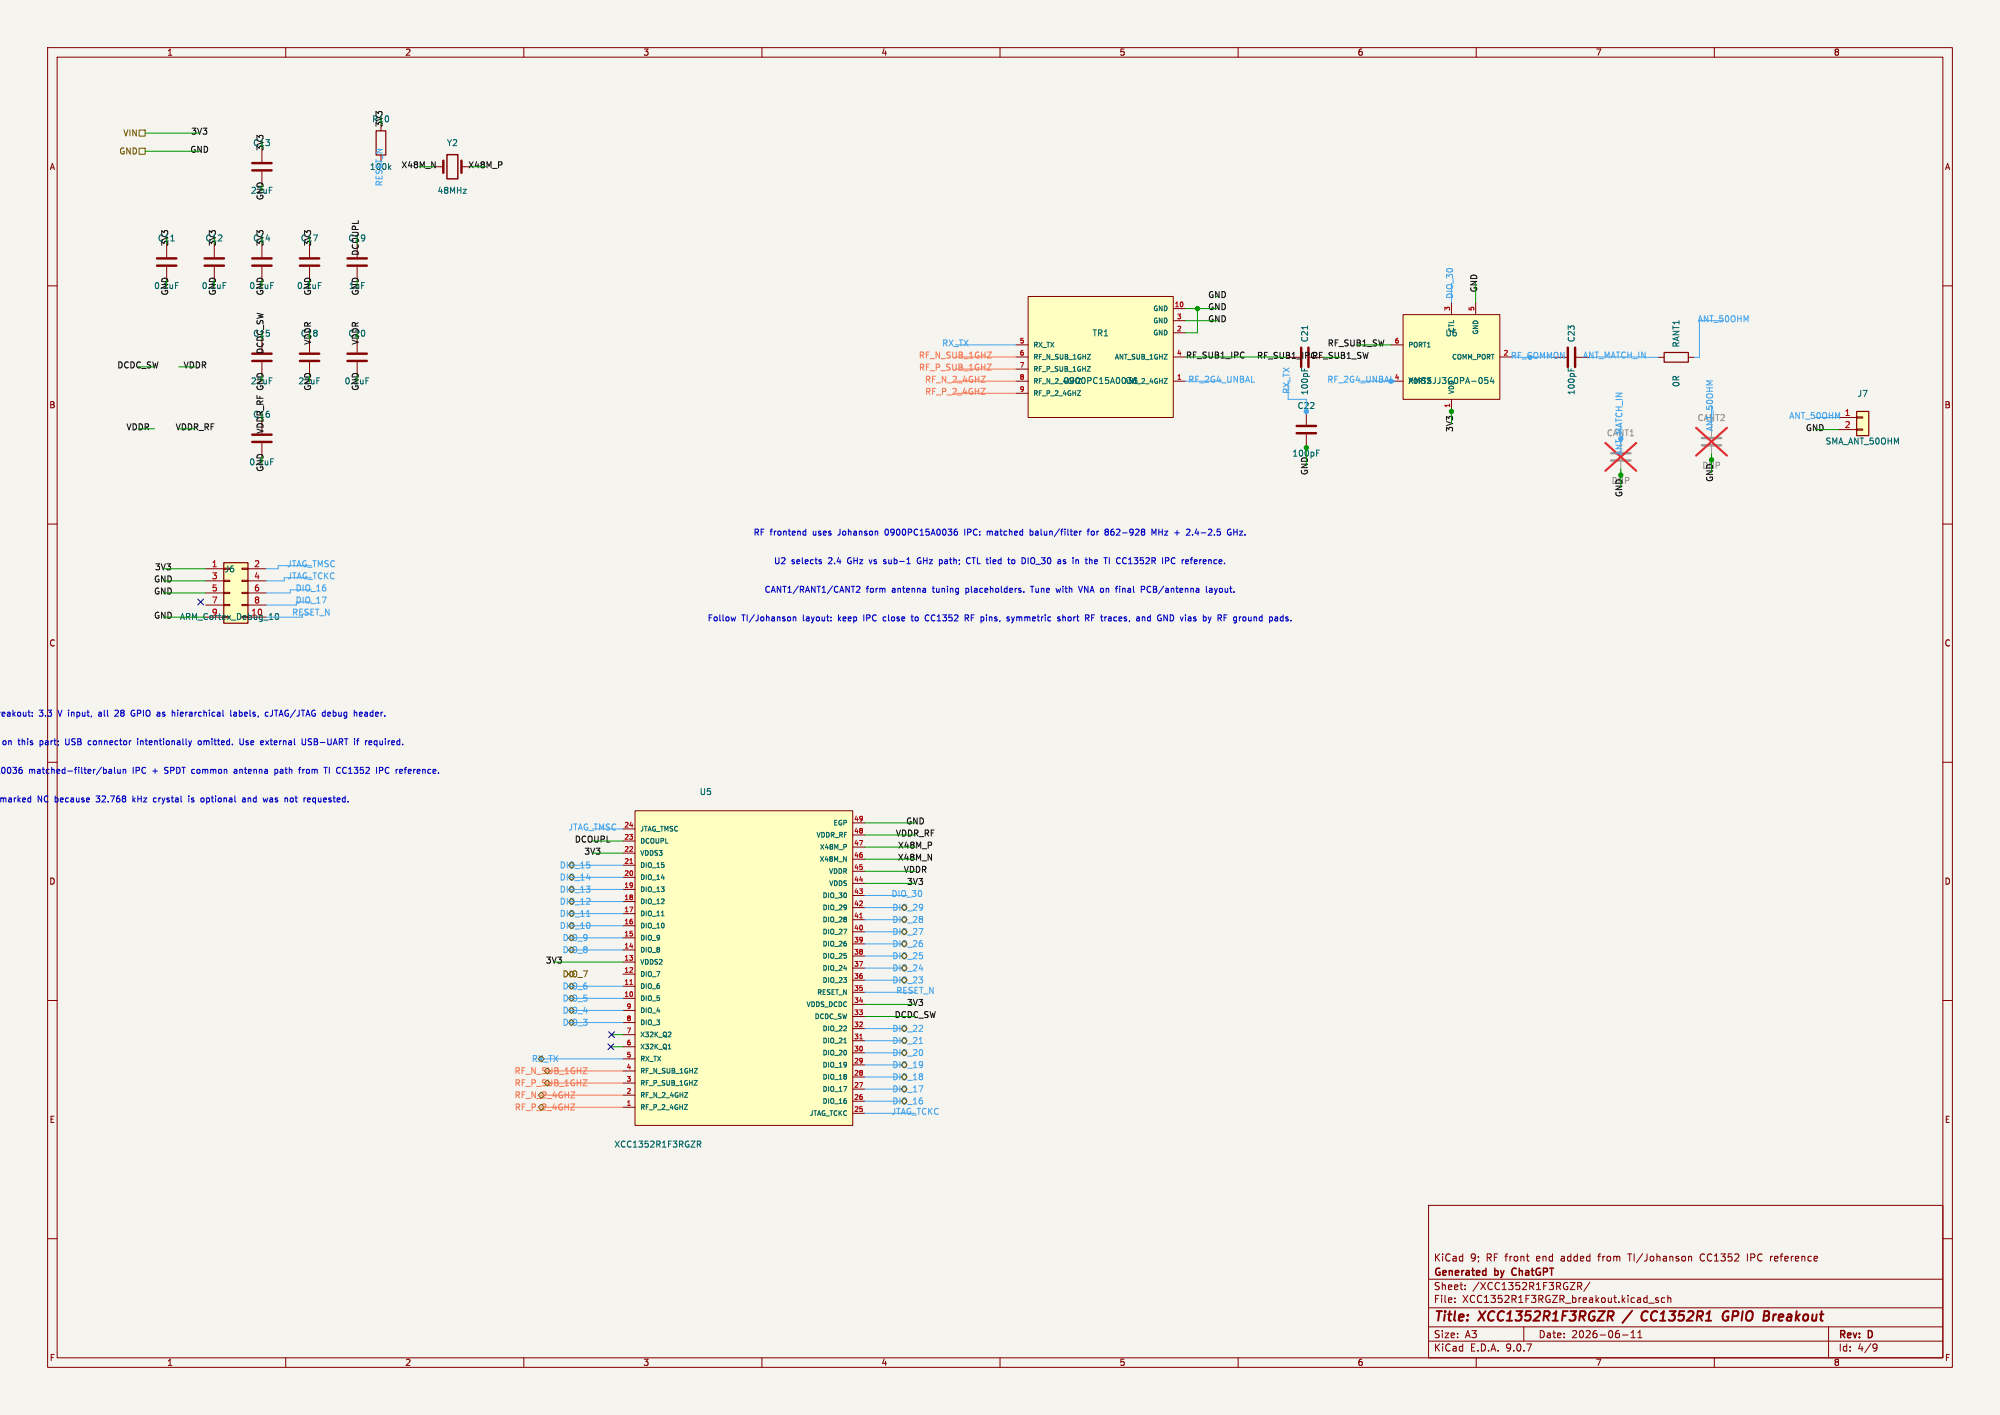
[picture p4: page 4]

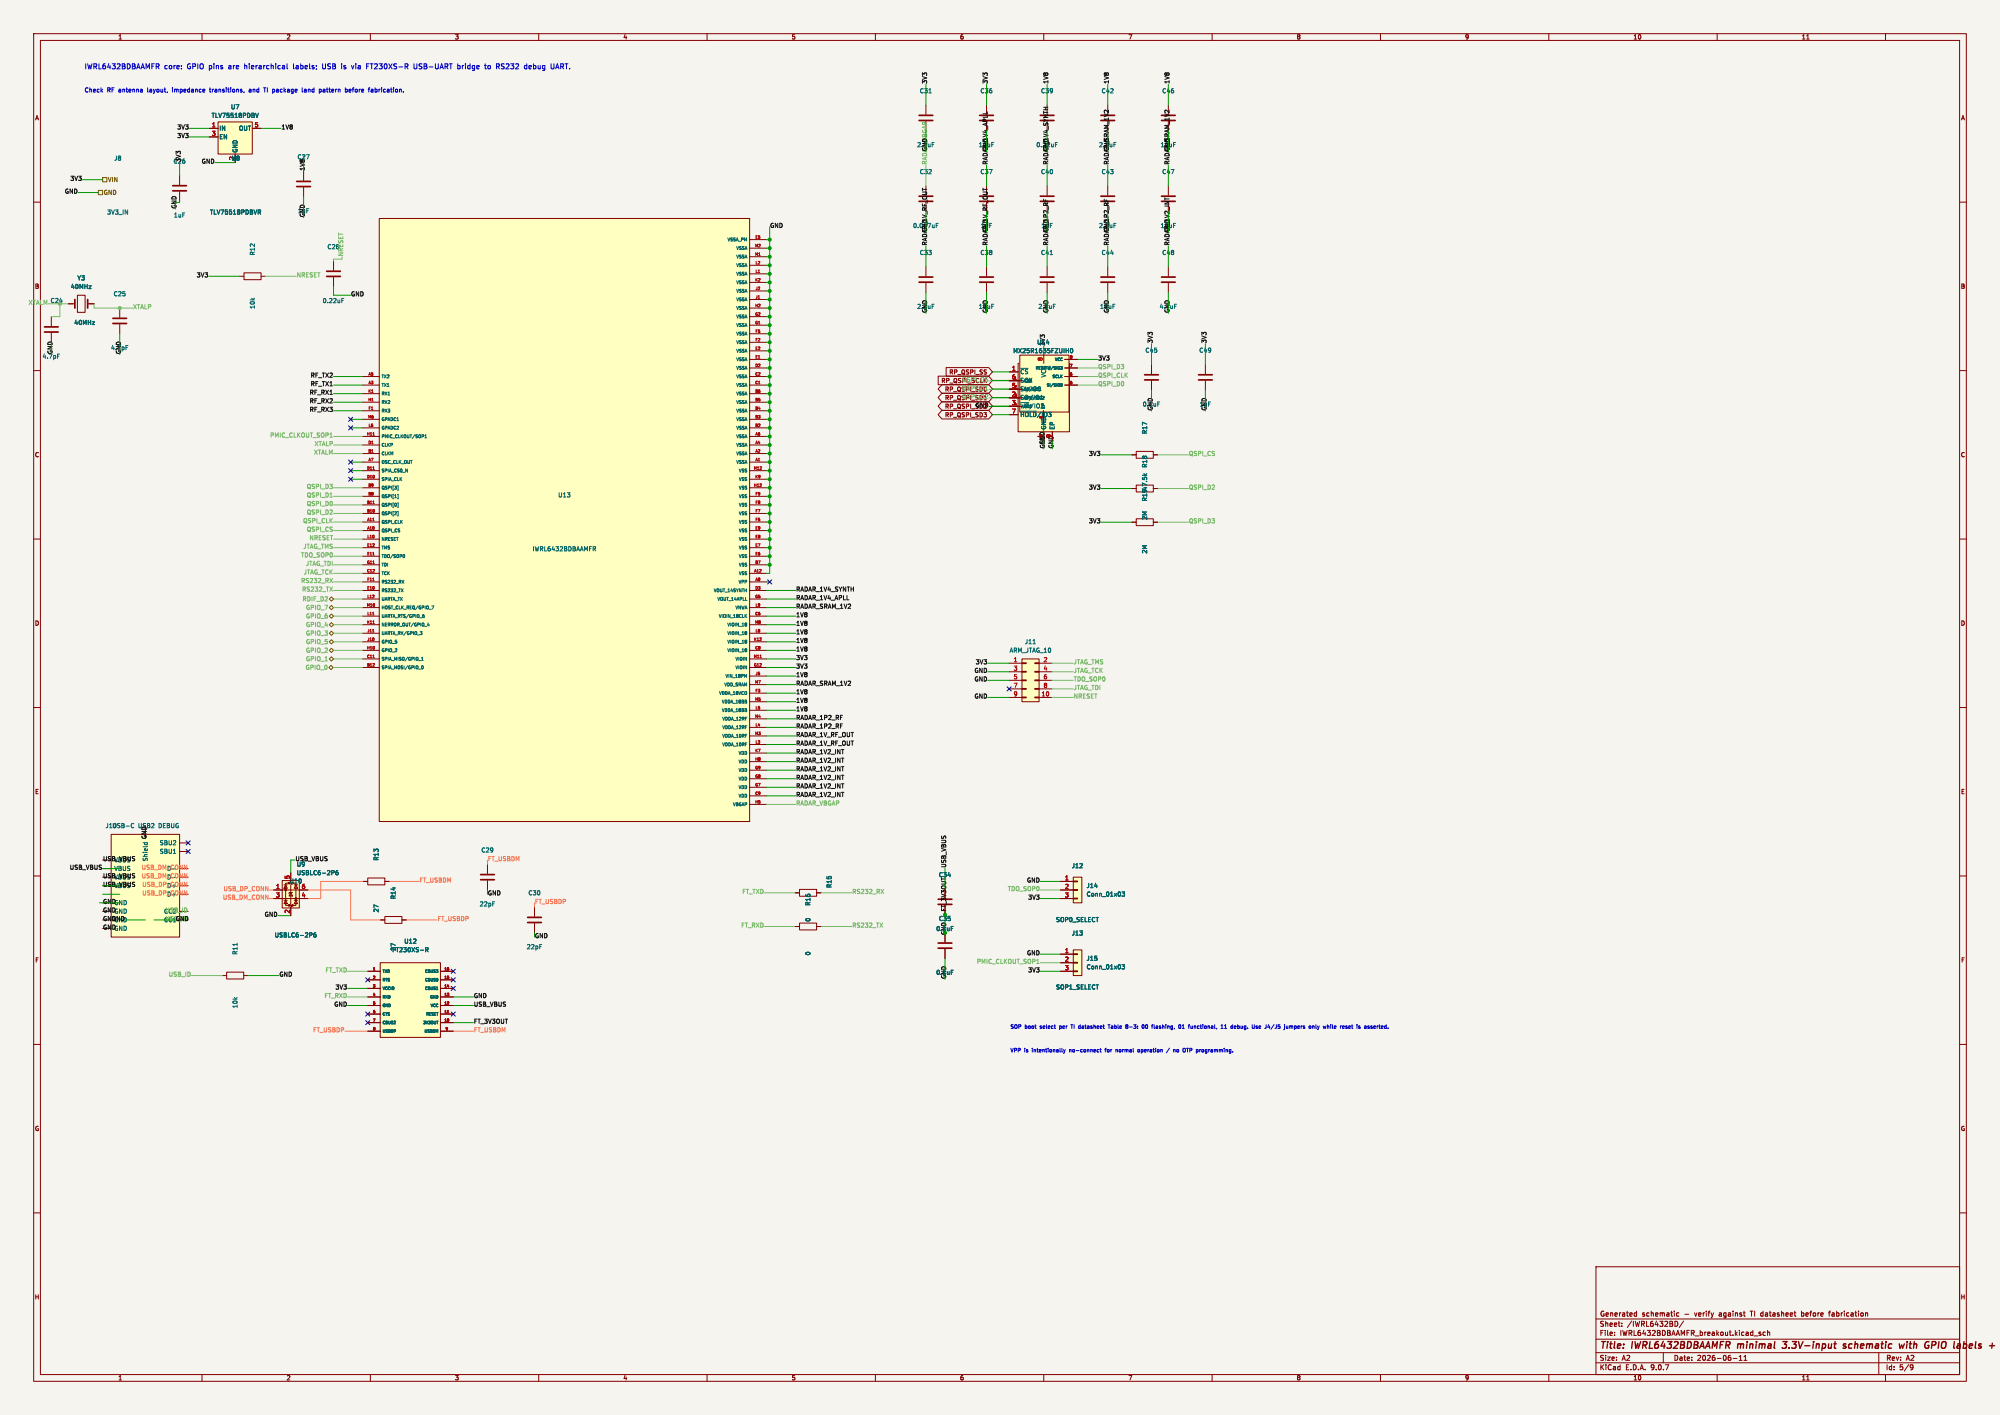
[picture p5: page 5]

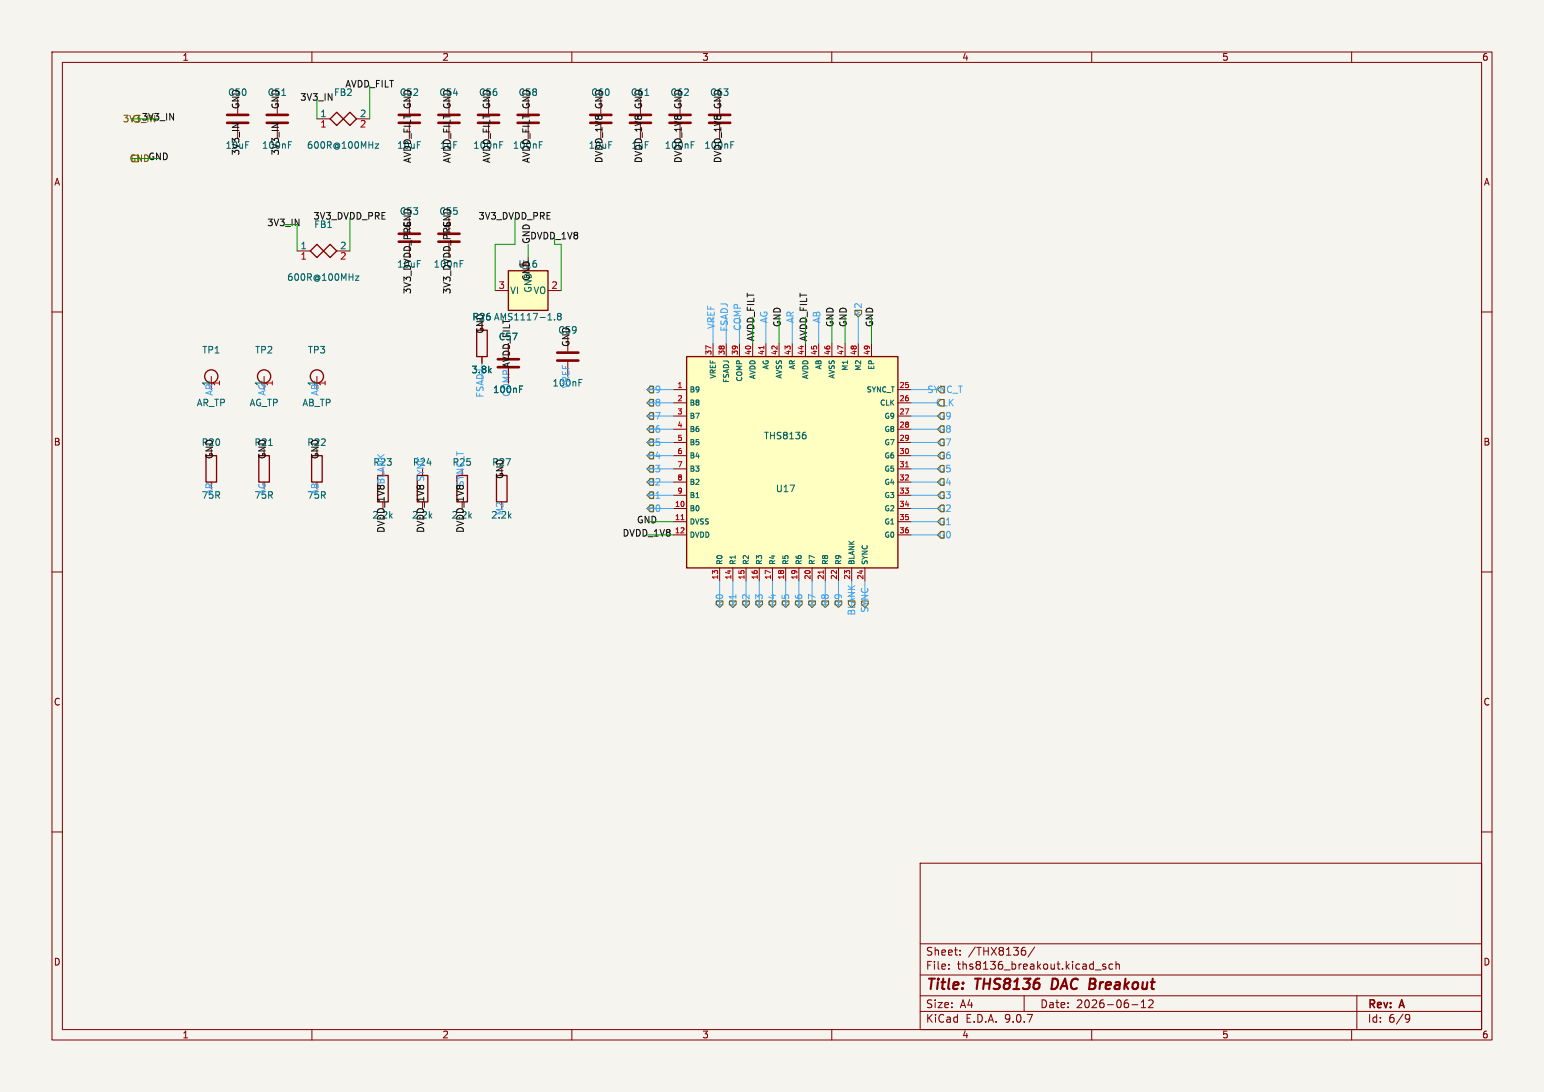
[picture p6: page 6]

Id: 6/9 Title: THS8136 DAC Breakout File: ths8136_breakout.kicad_sch Sheet: /THX8136/

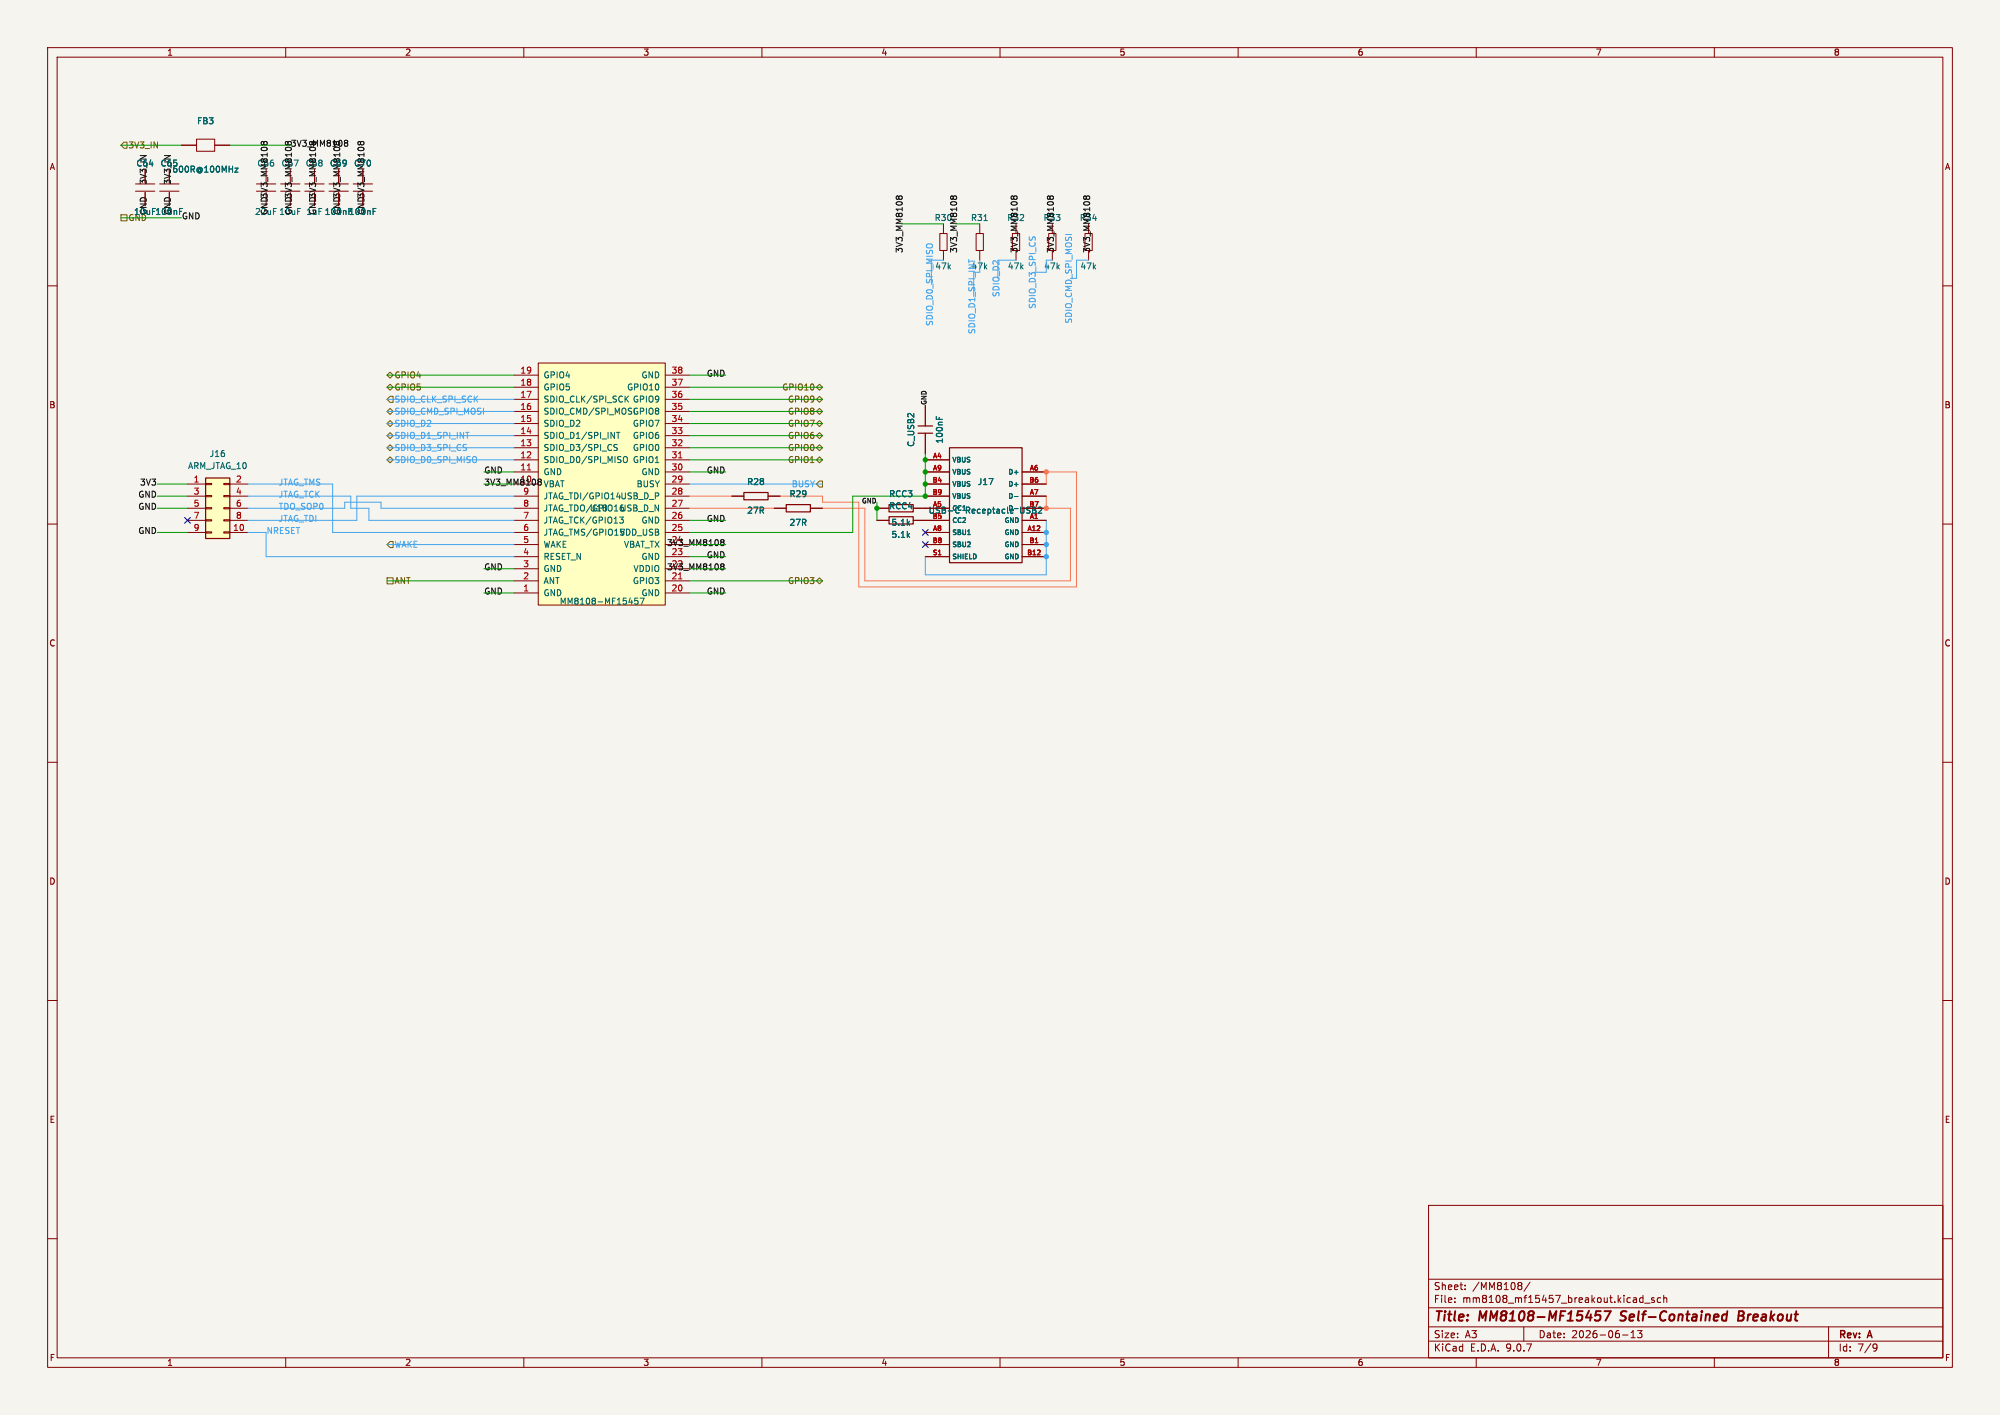
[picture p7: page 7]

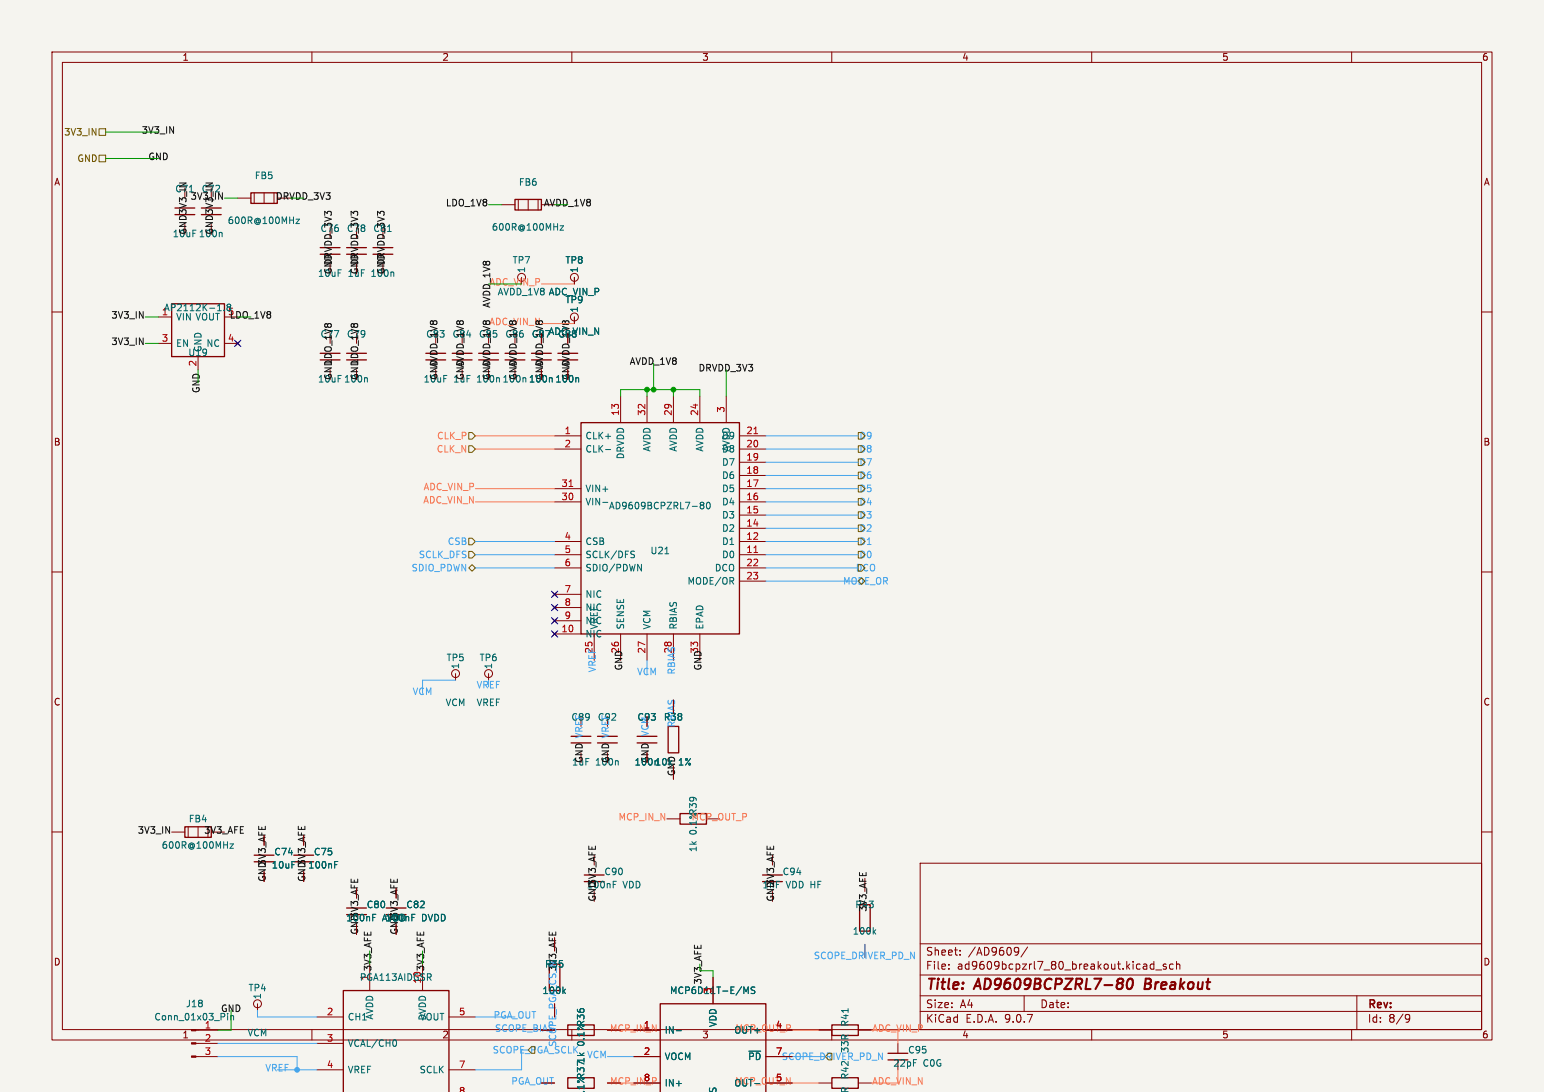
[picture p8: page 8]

3 OUT- 5 ~{PD} 7 OUT+ 4 U22 MCP6D11T-E/MS C93

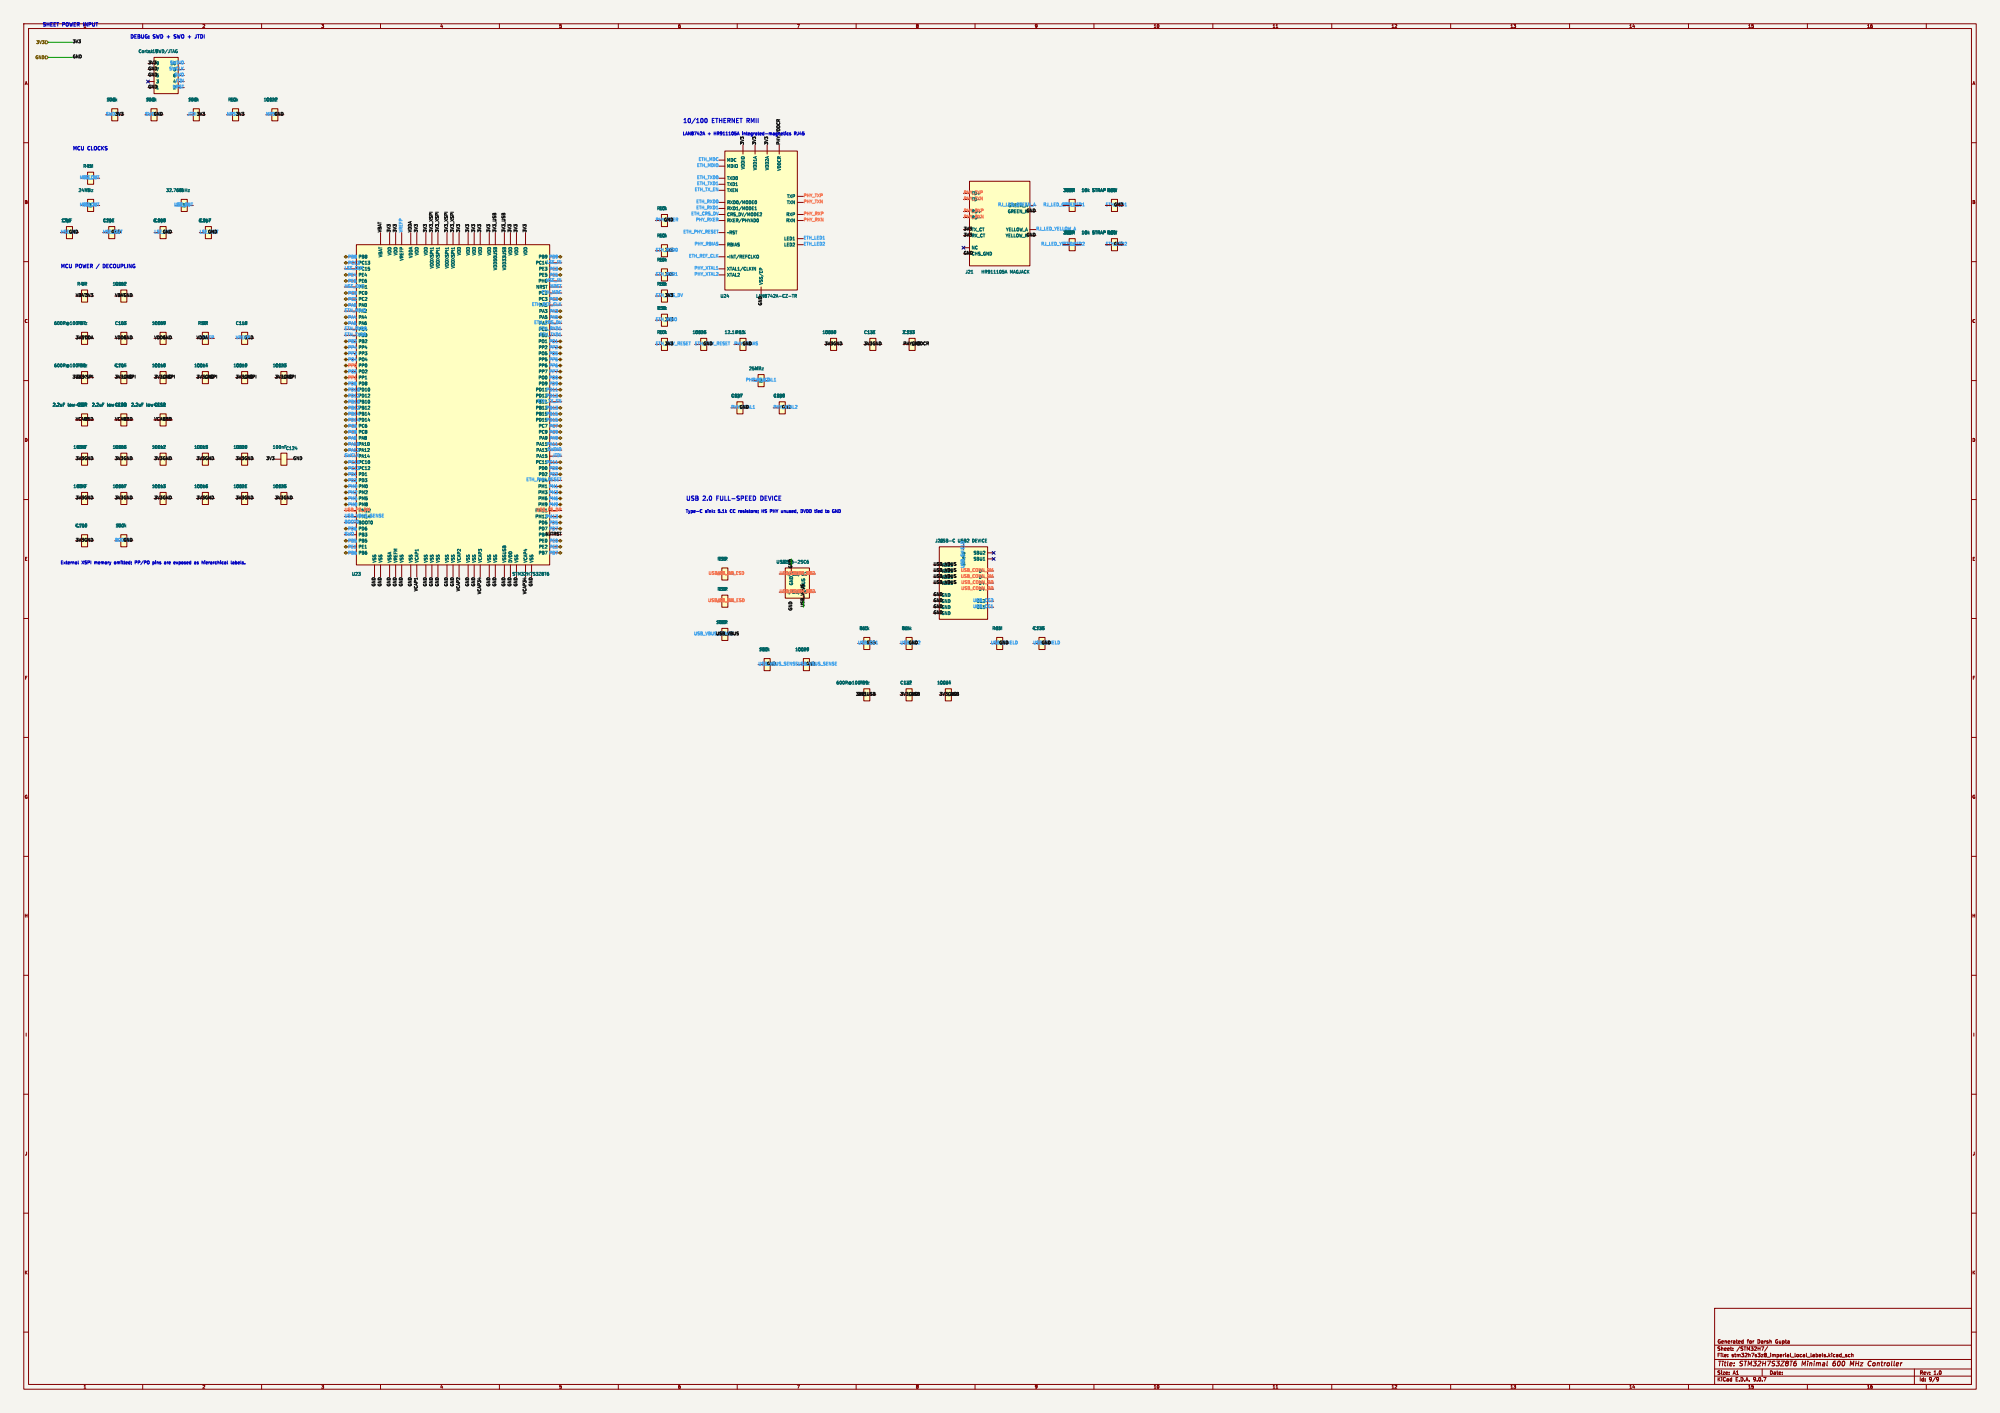
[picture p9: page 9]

DEBUG: SWD + SWO + JTDI

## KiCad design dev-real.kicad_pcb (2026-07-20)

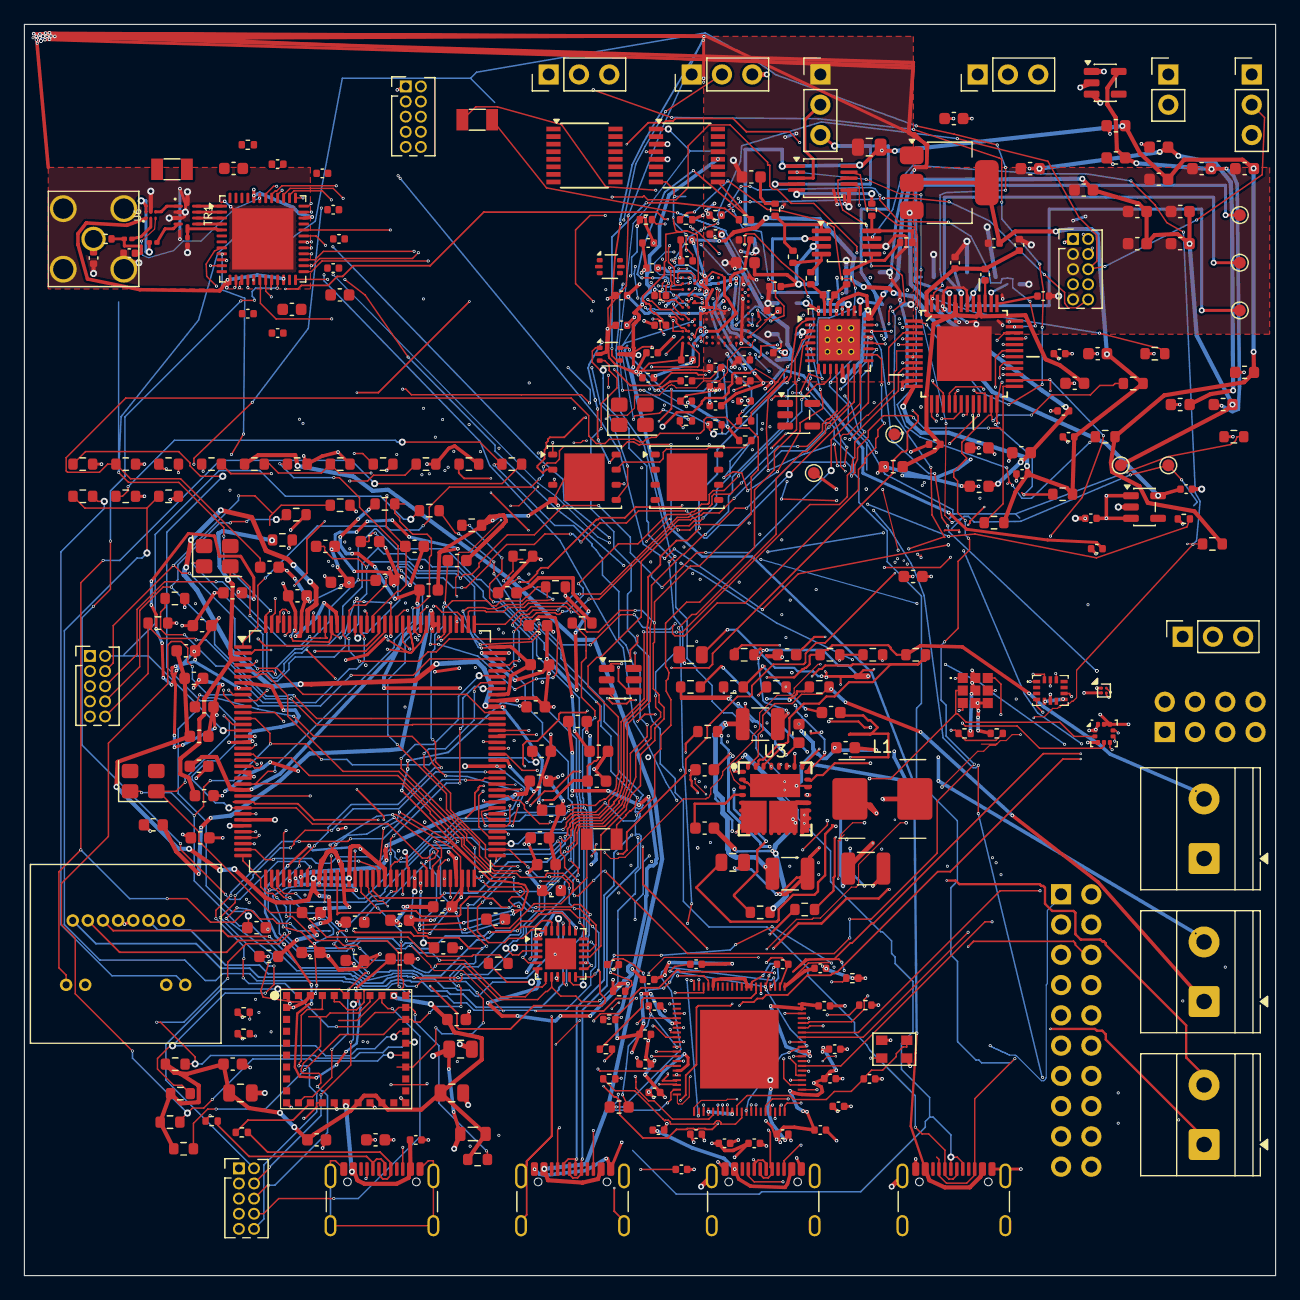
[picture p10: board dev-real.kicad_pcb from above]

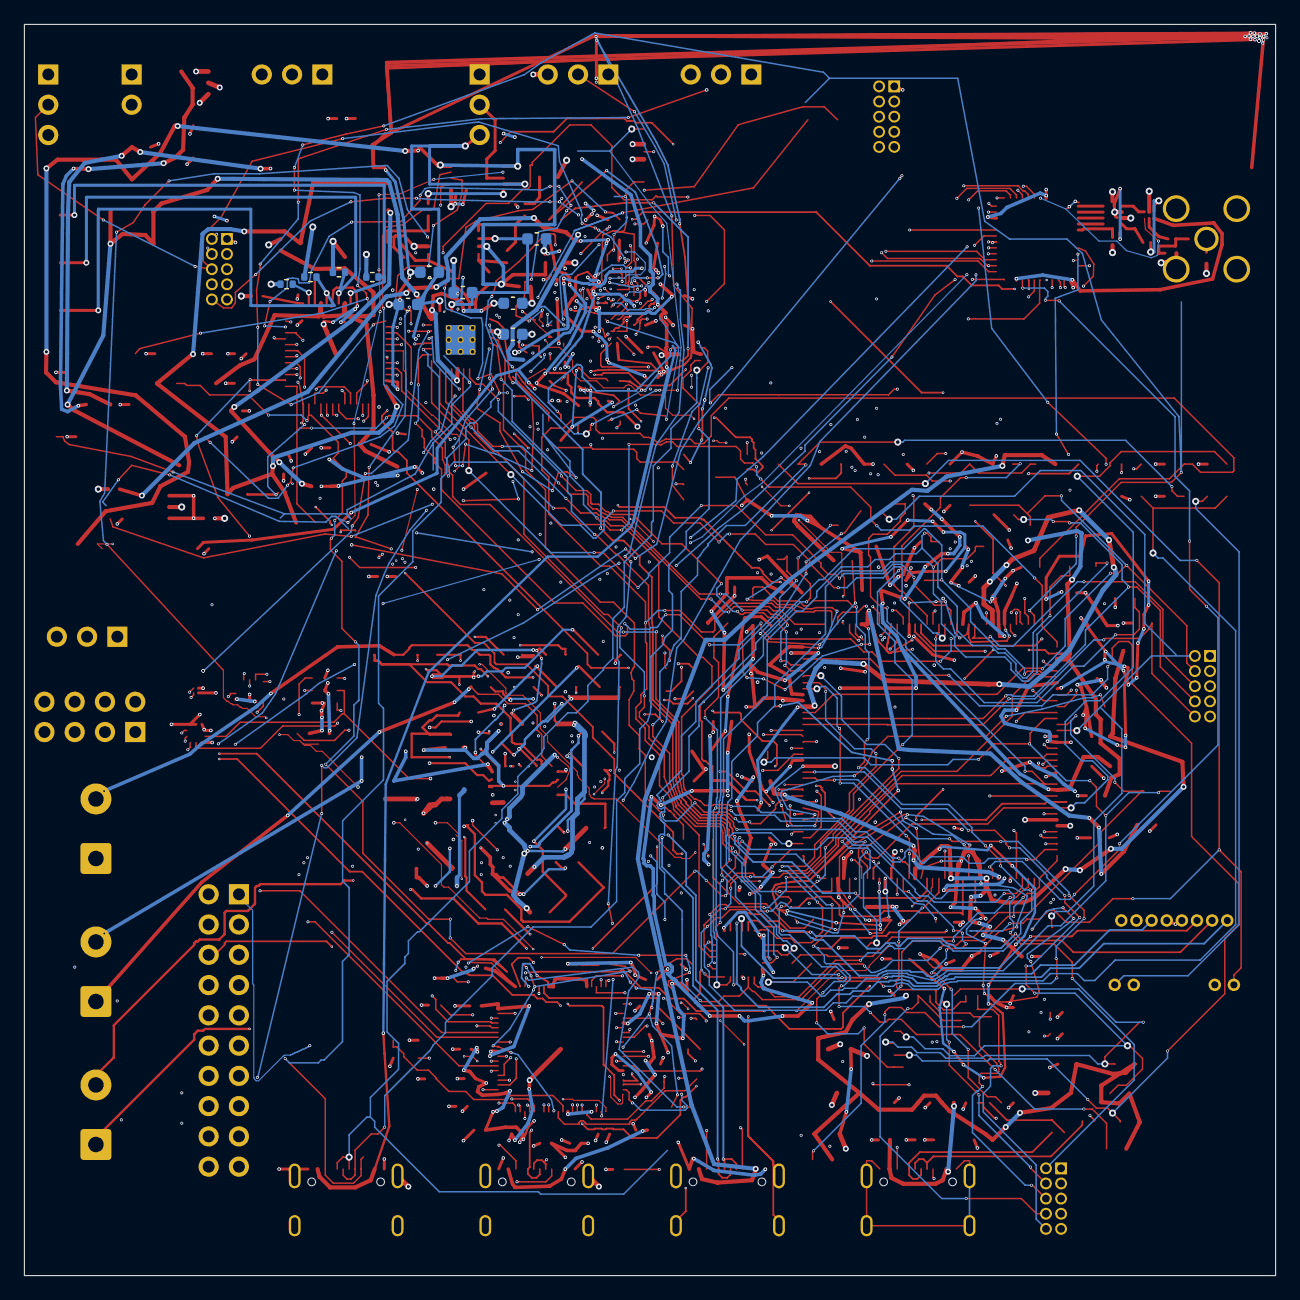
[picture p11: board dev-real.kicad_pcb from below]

Board: 4 copper layers, 105.0 x 105.0 mm, 318 parts (10 on the bottom side), 304 nets.

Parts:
C1: 4.7uF / >=10V; C_0805_2012Metric
C2: 2.2uF / >=10V; C_0603_1608Metric
C3, C5, C65, C69, C70, C75, C98, C99, C102, C106, C107, C109, C110, C112, C113, C114, C115, C116, C119, C120, C121, C122, C123, C124, C125, C126, C129, C130, C134: 100nF; C_0603_1608Metric
C4, C135: 4.7nF; C_0603_1608Metric
C6, C7: 15pF C0G; C_0402_1005Metric
C8, C9, C10: 4.7uF 6.3V X5R; C_0402_1005Metric
C11, C12, C14, C16, C17, C20, C34, C35, C45: 0.1uF; C_0402_1005Metric
C13, C15, C18: 22uF; C_0603_1608Metric
C19, C26, C27, C37, C40, C49, C54, C61: 1uF; C_0402_1005Metric
C21, C22, C23: 100pF; C_0201_0603Metric
C24, C25: 4.7pF; C_0402_1005Metric
C28, C39: 0.22uF; C_0402_1005Metric
C29, C30: 22pF; C_0402_1005Metric
C31, C33, C41, C42, C43: 2.2uF; C_0402_1005Metric
C32: 0.047uF; C_0402_1005Metric
C36, C38, C44, C46, C47: 10uF; C_0402_1005Metric
C48: 4.7uF; C_0402_1005Metric
C50, C52, C53, C60, C71, C76, C77, C83: 10uF; C_0603_1608Metric
C51, C55, C56, C57, C58, C59, C62, C63: 100nF; C_0402_1005Metric
C64, C67, C74: 10uF; C_0805_2012Metric
C66: 22uF; C_0805_2012Metric
C68, C78, C84, C89, C103, C118, C131, C132: 1uF; C_0603_1608Metric
C72, C79, C81, C85, C86, C87, C88, C92, C93: 100n; C_0603_1608Metric
C73: 100nF BIAS; C_0603_1608Metric
C80: 100nF AVDD; C_0603_1608Metric
C82: 100nF DVDD; C_0603_1608Metric
C90: 100nF VDD; C_0603_1608Metric
C91: 100nF VOCM; C_0603_1608Metric
C94: 1nF VDD HF; C_0402_1005Metric
C95: 22pF C0G; C_0402_1005Metric
C96, C101: 12pF; C_0603_1608Metric
C97, C105, C111: 2.2uF low-ESR; C_0603_1608Metric
C100, C104: 4.7uF; C_0603_1608Metric
C108, C117: 6.8pF; C_0603_1608Metric
C127, C128: 18pF; C_0603_1608Metric
C133: 2.2uF; C_0603_1608Metric
CANT1, CANT2: DNP; C_0402_1005Metric
CIN1: 10uF / >=10V; C_1210_3225Metric
CIN2: 39uF / >=10V; C_1210_3225Metric
COUT1: 47uF / >=6.3V; C_1210_3225Metric
COUT2: 100uF / >=6.3V; C_TODO_SELECT_100uF
CSS1: 12nF; C_0603_1608Metric
CSVIN1: 1uF / >=10V; C_0805_2012Metric
C_ADC1: 100nF; C_0402_1005Metric
C_DVDD1, C_DVDD2, C_DVDD3: 100nF; C_0402_1005Metric
C_IOBULK1: 10uF; C_0402_1005Metric
C_IOVDD1, C_IOVDD2, C_IOVDD3, C_IOVDD4, C_IOVDD5, C_IOVDD6, C_IOVDD7, C_IOVDD8: 100nF; C_0402_1005Metric
C_QSPI1: 100nF; C_0402_1005Metric
C_USB1, C_USB2: 100nF; C_0402_1005Metric
C_USBOTP1: 100nF; C_0402_1005Metric
FB1, FB2, FB4, FB5, FB6: 600R@100MHz; L_0603_1608Metric
FB3: 600R@100MHz; L_0805_2012Metric
FB7, FB8, FB9: 600R@100MHz; L_0603_1608Metric_Pad0.95x0.95mm_HandSolder
IC1: ICM-42670-P; ICM42670P
IC2: ENS161-BLGT_LGA9_T&R_1k5; ENS161BLGTLGA9TR1k5
J1: VIN_IN; TerminalBlock_Phoenix_MKDS-1,5-2_1x02_P5.00mm_Horizontal
J2: TP_EN_PG; TerminalBlock_Phoenix_MKDS-1,5-2_1x02_P5.00mm_Horizontal
J3: TP_SW_FB; TerminalBlock_Phoenix_MKDS-1,5-2_1x02_P5.00mm_Horizontal
J4, J17: USB-C Receptacle USB2; USB_C_Receptacle_GCT_USB4105-xx-A_16P_TopMnt_Horizontal
J5: Conn_01x03_Pin; PinSocket_1x03_P2.54mm_Vertical
J6: ARM_Cortex_Debug_10; PinHeader_2x05_P1.27mm_Vertical
J7: SMA_ANT_50OHM; SMA_Molex_73251-2120_EdgeMount_Horizontal
J8: 3V3_IN; PinHeader_1x02_P2.54mm_Vertical
J10: USB-C USB2 DEBUG; USB_C_Receptacle_GCT_USB4105-xx-A_16P_TopMnt_Horizontal
J11, J16: ARM_JTAG_10; PinHeader_2x05_P1.27mm_Vertical
J12: SOP0_SELECT; PinHeader_1x03_P2.54mm_Vertical
J13: SOP1_SELECT; PinHeader_1x03_P2.54mm_Vertical
J14, J15: Conn_01x03; PinHeader_1x03_P2.54mm_Vertical
J18: Conn_01x03_Pin; PinHeader_1x03_P2.54mm_Vertical
J19: Cortex SWD/JTAG; PinHeader_2x05_P1.27mm_Vertical
J20: USB-C USB2 DEVICE; USB_C_Receptacle_GCT_USB4105-xx-A_16P_TopMnt_Horizontal
J21: HR911105A MAGJACK; RJ45_Hanrun_HR911105A
J22: Conn_02x10_Counter_Clockwise; PinHeader_2x10_P2.54mm_Vertical
J23: Conn_02x04_Odd_Even; PinHeader_2x04_P2.54mm_Vertical
L1: 1uH LMLP07C7M1R0DTAS, Idc 15A / Isat 20A; L_Kyocera_LMLP07C7D_7.3x6.6mm
L2: 3.3uH Abracon AOTA-B201610S3R3-101-T; L_Abracon_AOTA-B201610S_2.0x1.6mm
NT1: AGND_to_PGND_single_point; NetTie-2_SMD_Pad0.5mm
R1, R35, R43, R46, R47, R48, R49, R62: 100k; R_0603_1608Metric
R2: 60.4k; R_0603_1608Metric
R3, R4: 2R; R_0603_1608Metric
R5: 24.3k; R_0603_1608Metric
R6, R70, R71: 1k; R_0402_1005Metric
R7, R8, R28, R29: 27R; R_0402_1005Metric
R9: 33R 1%; R_0402_1005Metric
R10: 100k; R_0402_1005Metric
R11, R12: 10k; R_0402_1005Metric
R13, R14: 27; R_0402_1005Metric
R15, R16: 0; R_0402_1005Metric
R17: 47.5k; R_0402_1005Metric
R18, R19: 2M; R_0402_1005Metric
R20, R21, R22: 75R; R_0402_1005Metric
R23, R24, R25, R27: 2.2k; R_0603_1608Metric
R26: 3.8k; R_0402_1005Metric
R30, R31, R32, R33, R34: 47k; R_0603_1608Metric
R36, R37, R39, R40: 1k 0.1%; R_0402_1005Metric
R38: 10k 1%; R_0603_1608Metric
R41, R42: 33R; R_0402_1005Metric
R44, R50: 0R; R_0603_1608Metric
R45, R65: 1M; R_0603_1608Metric
R51, R52, R53, R54, R55, R57: 10k; R_0603_1608Metric
R56: 1.5k; R_0603_1608Metric
R58, R59: 22R; R_0603_1608Metric
R60: 100R; R_0603_1608Metric
R61: 12.1k 1%; R_0603_1608Metric
R63, R64: 5.1k; R_0603_1608Metric
R66, R67: 330R; R_0603_1608Metric
R68, R69: 10k STRAP LOW; R_0603_1608Metric
RANT1: 0R; R_0402_1005Metric
RBOT1: 665R; R_0603_1608Metric
RCC1, RCC2, RCC3, RCC4: 5.1k; R_0402_1005Metric
RCL1: 2.21k; R_0603_1608Metric
REN1: 100k; R_0603_1608Metric
REXTVDD1: 0R DNP/NC option; R_0603_1608Metric
RPG1: 10k; R_0603_1608Metric
RTOP1: 3.00k; R_0603_1608Metric
TP1: AR_TP; TestPoint_Pad_D1.0mm
TP2: AG_TP; TestPoint_Pad_D1.0mm
TP3: AB_TP; TestPoint_Pad_D1.0mm
TP4, TP5: VCM; TestPoint_Pad_D1.0mm
TP6: VREF; TestPoint_Pad_D1.0mm
TP7: AVDD_1V8; TestPoint_Pad_D1.0mm
TR1: 0900PC15A0036; Johanson_0900PC15A0036_0805_10Pin
U1: MMC5633NJL; WLP-4_0.86x0.86mm_P0.4mm
U2: LPS22HH; ST_HLGA-10_2x2mm_P0.5mm_LayoutBorder3x2y
U3: MIC28516T-E/PHA; MIC28516-VQFN-32-6x6mm-P0.65-MultipleEP
U4: RP2350B; RP2350B_QFN80_10x10mm_P0.4mm_EP
U5: XCC1352R1F3RGZR; VQFN-48-1EP_7x7mm_P0.5mm_EP5.15x5.15mm
U6: XMSSJJ3G0PA-054; Murata_XMSSJJ3G0PA-054
U7: TLV75518PDBV; SOT-23-5
U8: TLV75518PDBVR; SOT-23-5
U9, U10: USBLC6-2P6; SOT-666
U11, U12: FT230XS-R; SSOP-16_3.9x4.9mm_P0.635mm
U13: IWRL6432BDBAAMFR; IWRL6432_AMF_FCCSP-102_6.45x6.45mm_P0.50mm
U14, U15: MX25R1635FZUIH0; WSON-8-1EP_6x5mm_P1.27mm_EP3.4x4mm
U16: AMS1117-1.8; SOT-223-3_TabPin2
U17: THS8136; QFP50P900X900X120-49N
U18: MM8108-MF15457; MM8108MF15457
U19: AP2112K-1.8; SOT-23-5
U20: PGA113AIDGSR; VSSOP-10_3x3mm_P0.5mm
U21: AD9609BCPZRL7-80; QFN-32-1EP_5x5mm_P0.5mm_EP3.45x3.45mm_ThermalVias
U22: MCP6D11T-E/MS; MSOP-8_3x3mm_P0.65mm
U23: STM32H7S3Z8T6; LQFP-144_20x20mm_P0.5mm
U24: LAN8742A-CZ-TR; QFN-24-1EP_4x4mm_P0.5mm_EP2.6x2.6mm
U25: USBLC6-2SC6; SOT-23-6
Y1: 12MHz ABM8-272-T3; Crystal_ABM8_3.2x2.5mm
Y2: 48MHz; Crystal_SMD_3225-2Pin_3.2x2.5mm
Y3: 40MHz; Crystal_SMD_3225-2Pin_3.2x2.5mm
Y4: 40MHz; Crystal_SMD_3225-4Pin_3.2x2.5mm
Y5: 24MHz; Crystal_SMD_3225-4Pin_3.2x2.5mm
Y6: 32.768kHz; Crystal_SMD_3215-2Pin_3.2x1.5mm
Y7: 25MHz; Crystal_SMD_3225-4Pin_3.2x2.5mm

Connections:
+3V3: C4.1, C8.1, C26.2, C31.2, C36.2, C45.2, C49.2, C50.2, C51.2, C64.1, C65.1, C71.2, C72.2, C98.1, C99.1, C100.1, C106.1, C107.1, C112.1, C113.1, C115.1, C116.1, C120.1, C121.1, C124.1, C125.1, C130.1, C131.1, COUT1.1, COUT2.1, C_ADC1.1, C_IOBULK1.1, C_IOVDD1.1, C_IOVDD2.1, C_IOVDD3.1, C_IOVDD4.1, C_IOVDD5.1, C_IOVDD6.1, C_IOVDD7.1, C_IOVDD8.1, C_QSPI1.1, C_USBOTP1.1, FB1.1, FB2.1, FB3.1, FB4.1, FB5.1, FB7.1, FB8.1, FB9.1, IC1.5 (VDDIO), IC1.8 (VDD), IC2.4 (VDD), IC2.5 (VDDIO), J6.1, J11.1, J14.3, J15.3, J19.9, J21.4, J21.5, J22.2, J22.3, J23.6, L1.2, R9.1, R12.1, R17.1, R18.1, R19.1, R44.2, R46.2, R49.2, R51.2, R53.2, R54.2, R55.2, R56.2, R57.2, R71.1, RTOP1.1, U1.B1 (VDD), U2.1 (Vdd_IO), U2.10 (VDD), U4.5, U4.15, U4.24, U4.29, U4.41, U4.50, U4.59, U4.60, U4.64, U4.68, U4.69, U4.76, U5.13 (VDDS2), U5.22 (VDDS3), U5.34 (VDDS_DCDC), U5.44 (VDDS), U6.1, U7.1 (IN), U7.3 (EN), U12.3 (VCCIO), U13.G12 (VIOIN), U13.M11 (VIOIN), U14.8 (VCC), U19.1 (VIN), U19.3 (EN), U23.7 (VDD), U23.17 (VDD), U23.31 (VDD), U23.41 (VDD), U23.69 (VDD), U23.81 (VDD), U23.88 (VDD), U23.100 (VDD), U23.108 (VDD), U23.123 (VDD), U23.133 (VDD), U23.139 (VDD), U24.1 (VDD2A), U24.9 (VDDIO), U24.19 (VDD1A)
/AD9609/3V3_AFE: C74.2, C75.2, C80.2, C82.2, C90.2, C94.2, FB4.2, R35.2, R43.2, U20.1 (AVDD), U20.10 (DVDD), U22.3 (VDD)
/AD9609/ADC_VIN_N: C95.1, R42.1, U21.30 (VIN-)
/AD9609/ADC_VIN_P: C95.2, R41.1, U21.31 (VIN+)
/AD9609/AVDD_1V8: C83.2, C84.2, C85.2, C86.2, C87.2, C88.2, FB6.2, TP7.1, U21.13 (DRVDD), U21.24 (AVDD), U21.29 (AVDD), U21.32 (AVDD)
/AD9609/CLK_N: U21.2 (CLK-), U23.61 (PP1)
/AD9609/CLK_P: U21.1 (CLK+), U23.55 (PP0)
/AD9609/CSB: U21.4 (CSB), U23.83 (PD15)
/AD9609/D0: U21.11 (D0), U23.104 (PD0)
/AD9609/D1: U21.12 (D1), U23.105 (PD1)
/AD9609/D2: U21.14 (D2), U23.71 (PD12)
/AD9609/D3: U21.15 (D3), U23.109 (PD3)
/AD9609/D4: U21.16 (D4), U23.129 (PD5)
/AD9609/D5: U21.17 (D5), U23.130 (PD6)
/AD9609/D6: U21.18 (D6), U23.131 (PD7)
/AD9609/D7: U21.19 (D7), U23.65 (PD8)
/AD9609/D8: U21.20 (D8), U23.66 (PD9)
/AD9609/D9: U21.21 (D9), U23.67 (PD10)
/AD9609/DCO: U21.22 (DCO), U23.68 (PD11)
/AD9609/DRVDD_3V3: C76.2, C78.2, C81.2, FB5.2, U21.3 (AVDD)
/AD9609/LDO_1V8: C77.2, C79.2, FB6.1, U19.5 (VOUT)
/AD9609/MCP_IN_N: R36.1, R39.2, U22.1 (IN-)
/AD9609/MCP_IN_P: R37.1, R40.2, U22.8 (IN+)
/AD9609/MCP_OUT_N: R40.1, R42.2, U22.5 (OUT-)
/AD9609/MCP_OUT_P: R39.1, R41.2, U22.4 (OUT+)
/AD9609/MODE_OR: U21.23 (MODE/OR), U23.82 (PD14)
/AD9609/PGA_OUT: R37.2, U20.5 (VOUT)
/AD9609/RBIAS: R38.2, U21.28 (RBIAS)
/AD9609/SCLK_DFS: U21.5 (SCLK/DFS), U23.72 (PD13)
/AD9609/SCOPE_BIAS: C73.2, R36.2
/AD9609/SCOPE_DRIVER_PD_N: R43.1, U22.7 (~PD), U23.54 (PP5)
/AD9609/SCOPE_PGA_CS_N: R35.1, U20.9 (~CS), U23.47 (PP4)
/AD9609/SCOPE_PGA_DIO: U20.8 (DIO), U23.49 (PP3)
/AD9609/SCOPE_PGA_SCLK: U20.7 (SCLK), U23.48 (PP2)
/AD9609/SDIO_PDWN: U21.6 (SDIO/PDWN), U23.58 (PP6)
/AD9609/VCM: C91.2, C93.2, TP5.1, U21.27 (VCM), U22.2 (VOCM)
/AD9609/VREF: C89.2, C92.2, J18.3, TP6.1, U20.4 (VREF), U21.25 (VREF)
/IWRL6432BD/1V8: C27.2, C39.2, C42.2, C46.2, U7.5 (OUT), U13.C6 (VIOIN_18CLK), U13.C8 (VIOIN_18), U13.F3 (VDDA_18VCO), U13.J5 (VIN_18PM), U13.K12 (VIOIN_18), U13.L5 (VDDA_18BB), U13.L8 (VIOIN_18), U13.M5 (VDDA_18BB), U13.M8 (VIOIN_18)
/IWRL6432BD/FT_RXD: R16.1, U12.4 (RXD)
/IWRL6432BD/FT_TXD: R15.1, U12.1 (TXD)
/IWRL6432BD/FT_USBDM: C29.2, R13.2, U12.9 (USBDM)
/IWRL6432BD/FT_USBDP: C30.2, R14.2, U12.8 (USBDP)
/IWRL6432BD/GPIO_0: U4.16, U13.B12 (SPIA_MOSI/GPIO_0)
/IWRL6432BD/GPIO_1: U4.17, U13.C11 (SPIA_MISO/GPIO_1)
/IWRL6432BD/GPIO_2: U4.18, U13.H10 (GPIO_2)
/IWRL6432BD/GPIO_3: U4.19, U13.J11 (UARTA_RX/GPIO_3)
/IWRL6432BD/GPIO_4: U4.20, U13.K11 (NERROR_OUT/GPIO_4)
/IWRL6432BD/GPIO_5: U4.21, U13.J10 (GPIO_5)
/IWRL6432BD/GPIO_6: U4.22, U13.L11 (UARTA_RTS/GPIO_6)
/IWRL6432BD/GPIO_7: U4.23, U13.M10 (HOST_CLK_REQ/GPIO_7)
/IWRL6432BD/JTAG_TCK: J11.4, U13.C12 (TCK)
/IWRL6432BD/JTAG_TDI: J11.8, U13.G11 (TDI)
/IWRL6432BD/JTAG_TMS: J11.2, U13.E12 (TMS)
/IWRL6432BD/NRESET: C28.2, J11.10, R12.2, U13.L10 (NRESET)
/IWRL6432BD/PMIC_CLKOUT_SOP1: J15.2, U13.H11 (PMIC_CLKOUT/SOP1)
/IWRL6432BD/QSPI_CLK: U13.A11 (QSPI_CLK), U14.6 (SCLK)
/IWRL6432BD/QSPI_CS: R17.2, U13.A10 (QSPI_CS), U14.1 (CS#)
/IWRL6432BD/QSPI_D0: U13.B11 (QSPI[0]), U14.5 (SI/SIO0)
/IWRL6432BD/QSPI_D1: U13.B8 (QSPI[1]), U14.2 (SO/SIO1)
/IWRL6432BD/QSPI_D2: R18.2, U13.B10 (QSPI[2]), U14.3 (WP#/SIO2)
/IWRL6432BD/QSPI_D3: R19.2, U13.B9 (QSPI[3]), U14.7 (RESET#/SIO3)
/IWRL6432BD/RADAR_1P2_RF: C41.2, C44.2, U13.L4 (VDDA_12RF), U13.M4 (VDDA_12RF)
/IWRL6432BD/RADAR_1V2_INT: C48.2, U13.C9 (VDD), U13.G7 (VDD), U13.G8 (VDD), U13.G9 (VDD), U13.H8 (VDD), U13.K7 (VDD)
/IWRL6432BD/RADAR_1V4_APLL: C37.2, U13.G5 (VOUT_14APLL)
/IWRL6432BD/RADAR_1V4_SYNTH: C40.2, U13.D3 (VOUT_14SYNTH)
/IWRL6432BD/RADAR_1V_RF_OUT: C33.2, C38.2, U13.L3 (VDDA_10RF), U13.M3 (VDDA_10RF)
/IWRL6432BD/RADAR_SRAM_1V2: C43.2, C47.2, U13.L9 (VNWA), U13.M7 (VDD_SRAM)
/IWRL6432BD/RADAR_VBGAP: C32.2, U13.H5 (VBGAP)
/IWRL6432BD/RDIF_D2: U4.25, U13.L12 (UARTA_TX)
/IWRL6432BD/RS232_RX: R15.2, U13.F11 (RS232_RX)
/IWRL6432BD/RS232_TX: R16.2, U13.E10 (RS232_TX)
/IWRL6432BD/TDO_SOP0: J11.6, J14.2, U13.E11 (TDO/SOP0)
/IWRL6432BD/USB_DM_CONN: J10.A7 (D-), J10.B7 (D-), U9.3 (I/O2)
/IWRL6432BD/USB_DP_CONN: J10.A6 (D+), J10.B6 (D+), U9.1 (I/O1)
/IWRL6432BD/USB_ID: J10.A5 (CC1), J10.B5 (CC2), R11.1
/IWRL6432BD/USB_VBUS: C34.2, J10.A4 (VBUS), J10.A9 (VBUS), J10.B4 (VBUS), J10.B9 (VBUS), U9.5 (VBUS), U12.12 (VCC)
/IWRL6432BD/XTALM: C24.2, U13.B1 (CLKM), Y3.1
/IWRL6432BD/XTALP: C25.2, U13.D1 (CLKP), Y3.2
/MM8108/3V3_MM8108: C66.1, C67.1, C68.1, C69.1, C70.1, FB3.2, R30.1, R31.1, R32.1, R33.1, R34.1, U18.10 (VBAT), U18.22 (VDDIO), U18.24 (VBAT_TX)
/MM8108/BUSY: U18.29 (BUSY), U23.59 (PO2)
/MM8108/JTAG_TCK: J16.4, U18.7 (JTAG_TCK/GPIO13)
/MM8108/JTAG_TDI: J16.8, U18.9 (JTAG_TDI/GPIO14)
/MM8108/JTAG_TMS: J16.2, U18.6 (JTAG_TMS/GPIO15)
/MM8108/NRESET: J16.10, U18.4 (RESET_N)
/MM8108/SDIO_CLK_SPI_SCK: U18.17 (SDIO_CLK/SPI_SCK), U23.103 (PC12)
/MM8108/SDIO_CMD_SPI_MOSI: R34.2, U18.16 (SDIO_CMD/SPI_MOSI), U23.106 (PD2)
/MM8108/SDIO_D0_SPI_MISO: R30.2, U18.12 (SDIO_D0/SPI_MISO), U23.86 (PC8)
/MM8108/SDIO_D1_SPI_INT: R31.2, U18.14 (SDIO_D1/SPI_INT), U23.87 (PC9)
/MM8108/SDIO_D2: R32.2, U18.15 (SDIO_D2), U23.101 (PC10)
/MM8108/SDIO_D3_SPI_CS: R33.2, U18.13 (SDIO_D3/SPI_CS), U23.102 (PC11)
/MM8108/TDO_SOP0: J16.6, U18.8 (JTAG_TDO/GPIO16)
/MM8108/WAKE: U18.5 (WAKE), U23.53 (PO4)
/Power/AGND: CSS1.2, CSVIN1.2, NT1.1, R2.2, RBOT1.2, U3.28
/Power/BST: C3.1, U3.4
/Power/EN: J2.2, REN1.2, U3.24
/Power/EXTVDD: REXTVDD1.1, U3.23
/Power/FB: C4.2, C5.2, J3.1, RBOT1.1, RTOP1.2, U3.27
/Power/FREQ: R1.2, R2.1, U3.25
/Power/ILIM: RCL1.1, U3.1
/Power/MODE_SS: CSS1.1, U3.26
/Power/PG: J2.1, RPG1.2, U3.32
/Power/PVDD: C1.1, R4.2, U3.21
/Power/RIPPLE_INJ: C5.1, R5.2
/Power/SVIN: CSVIN1.1, R3.2, U3.31
/Power/SW: C3.2, J3.2, L1.1, R5.1, RCL1.2, U3.3, U3.12, U3.13, U3.14, U3.15, U3.20
/Power/VDD: C2.1, R4.1, REN1.1, RPG1.1, U3.30
/Power/VIN: CIN1.1, CIN2.1, J1.2, R1.1, R3.1, U3.5, U3.6, U3.7, U3.8, U3.9, U3.10, U3.11
/RP2350/+1V1: C9.1, C_DVDD1.1, C_DVDD2.1, C_DVDD3.1, L2.2, U4.10, U4.32, U4.51, U4.65
/RP2350/CC1: J4.A5 (CC1), RCC1.1
/RP2350/CC2: J4.B5 (CC2), RCC2.1
/RP2350/GPIO0: U4.77, U23.93 (PA11)
/RP2350/GPIO1: U4.78, U23.94 (PA12)
/RP2350/GPIO2: U4.79, U5.10 (DIO_5)
/RP2350/GPIO3: U4.80, U5.14 (DIO_8)
/RP2350/GPIO4: U4.1, U5.11 (DIO_6)
/RP2350/GPIO6: U4.3, U5.15 (DIO_9)
/RP2350/GPIO7: U4.4, U5.9 (DIO_4)
/RP2350/GPIO8: U4.6, U5.8 (DIO_3)
/RP2350/GPIO9: U4.7, U23.29 (PA3)
/RP2350/GPIO10: U4.8, U23.32 (PA4)
/RP2350/GPIO11: U4.9, U23.33 (PA5)
/RP2350/GPIO12: U4.11, U23.34 (PA6)
/RP2350/GPIO13: U4.12, U23.90 (PA8)
/RP2350/GPIO14: U4.13, U23.91 (PA9)
/RP2350/GPIO15: U4.14, U23.92 (PA10)
/RP2350/GPIO25: U2.7 (INT_DRDY), U4.26
/RP2350/GPIO26: IC1.4 (INT1_/_INT), U4.27
/RP2350/GPIO27: IC1.9 (INT2), U4.28
/RP2350/GPIO28: IC2.6 (INTN), U4.36
/RP2350/GPIO29: J23.4, U4.37
/RP2350/GPIO30: U1.B2 (SDA), U4.38
/RP2350/GPIO31: U1.A2 (SCL), U4.39
/RP2350/GPIO32: IC1.1 (AP_SDO_/_AP_AD0), U4.40
/RP2350/GPIO33: IC1.12 (AP_CS), U4.42
/RP2350/GPIO34: IC1.13 (AP_SCL_/_AP_SCLK), U4.43
/RP2350/GPIO35: IC1.14 (AP_SDA_/_AP_SDIO_/_AP_SDI), U4.44
/RP2350/GPIO36: IC2.1 (MOSI_/_SDA), U2.4 (SDA), U4.45
/RP2350/GPIO37: IC2.2 (SCLK_/_SCL), U2.2 (SCL), U4.46
/RP2350/GPIO38: IC2.7 (CSN), U4.47
/RP2350/GPIO39: U2.6 (~CS), U4.48
/RP2350/GPIO40_ADC0: U2.5 (SA0), U4.49
/RP2350/GPIO41_ADC1: IC2.3 (MISO_/_ADDR), U4.52
/RP2350/GPIO42_ADC2: R70.1, R71.2, U4.53
/RP2350/GPIO43_ADC3: J23.7, U4.54
/RP2350/GPIO44_ADC4: J23.5, U4.55
/RP2350/GPIO45_ADC5: J23.3, U4.56
/RP2350/GPIO46_ADC6: J23.1, U4.57
/RP2350/GPIO47_ADC7: J23.2, U4.58
/RP2350/SWCLK: J5.3, U4.33
/RP2350/SWDIO: J5.1, U4.34
/RP2350/USB_DM_IC: R8.1, U4.66
/RP2350/USB_DP_IC: R7.1, U4.67
/RP2350/USB_D_N_CONN: J4.A7 (D-), J4.B7 (D-), R8.2
/RP2350/USB_D_P_CONN: J4.A6 (D+), J4.B6 (D+), R7.2
/RP2350/USB_VBUS: C_USB1.1, J4.A4 (VBUS), J4.A9 (VBUS), J4.B4 (VBUS), J4.B9 (VBUS)
/RP2350/VREG_AVDD: C10.1, R9.2, U4.61
/RP2350/VREG_LX: L2.1, U4.63
/RP2350/XIN: C6.1, U4.30, Y1.2 (GND)
/RP2350/XOUT: R6.1, U4.31
/RP2350/XOUT_XTAL: C7.1, R6.2, Y1.4 (GND)
/STM32H7/3V3_USB: C132.1, C134.1, FB9.2, U23.115 (VDD50USB), U23.116 (VDD33USB)
/STM32H7/3V3_XSPI: C104.1, C110.1, C114.1, C119.1, C123.1, FB8.2, U23.45 (VDDXSPI1), U23.51 (VDDXSPI1), U23.57 (VDDXSPI1), U23.63 (VDDXSPI1)
/STM32H7/BOOT0: R47.1, U23.128 (BOOT0)
/STM32H7/ETH_CRS_DV: R55.1, U23.35 (PA7), U24.11 (CRS_DV/MODE2)
/STM32H7/ETH_LED1: R66.1, R68.1, U24.3 (LED1)
/STM32H7/ETH_LED2: R67.1, R69.1, U24.2 (LED2)
/STM32H7/ETH_MDC: U23.19 (PC1), U24.13 (MDC)
/STM32H7/ETH_MDIO: R56.1, U23.28 (PA2), U24.12 (MDIO)
/STM32H7/ETH_PHY_RESET: C126.1, R57.1, U23.110 (PD4), U24.15 (~RST)
/STM32H7/ETH_REF_CLK: U23.27 (PA1), U24.14 (~INT/REFCLKO)
/STM32H7/ETH_RXD0: R53.1, U23.36 (PC4), U24.8 (RXD0/MODE0)
/STM32H7/ETH_RXD1: R54.1, U23.37 (PC5), U24.7 (RXD1/MODE1)
/STM32H7/ETH_TXD0: U23.38 (PB0), U24.17 (TXD0)
/STM32H7/ETH_TXD1: U23.39 (PB1), U24.18 (TXD1)
/STM32H7/ETH_TX_EN: U23.74 (PB11), U24.16 (TXEN)
/STM32H7/HSE_IN: C96.1, R45.1, U23.13 (PH0), Y5.1
/STM32H7/HSE_OUT: C101.1, R45.2, U23.14 (PH1), Y5.2
/STM32H7/JTDI: J19.4, R49.1, U23.97 (PA15)
/STM32H7/LSE_IN: C108.1, U23.5 (PC14), Y6.1
/STM32H7/LSE_OUT: C117.1, U23.6 (PC15), Y6.2
/STM32H7/NRST: C122.1, J19.2, R51.1, U23.15 (NRST)
/STM32H7/PB2: U17.3 (B7), U23.40 (PB2)
/STM32H7/PB5: U17.4 (B6), U23.136 (PB5)
/STM32H7/PB6: U17.5 (B5), U23.143 (PB6)
/STM32H7/PB10: U17.26 (CLK), U23.73 (PB10)
/STM32H7/PB13: U17.20 (R7), U23.76 (PB13)
/STM32H7/PB14: U17.21 (R8), U23.77 (PB14)
/STM32H7/PB15: U17.22 (R9), U23.78 (PB15)
/STM32H7/PC0: U17.10 (B0), U23.18 (PC0)
/STM32H7/PC2: U17.9 (B1), U23.20 (PC2)
/STM32H7/PC3: U17.8 (B2), U23.21 (PC3)
/STM32H7/PC6: U17.7 (B3), U23.84 (PC6)
/STM32H7/PC7: U17.6 (B4), U23.85 (PC7)
/STM32H7/PC13: U17.27 (G9), U23.4 (PC13)
/STM32H7/PE0: U17.13 (R0), U23.140 (PE0)
/STM32H7/PE1: U17.14 (R1), U23.141 (PE1)
/STM32H7/PE2: U17.15 (R2), U23.142 (PE2)
/STM32H7/PE3: U17.16 (R3), U23.9 (PE3)
/STM32H7/PE4: U17.17 (R4), U23.10 (PE4)
/STM32H7/PE5: U17.18 (R5), U23.11 (PE5)
/STM32H7/PE6: U17.19 (R6), U23.12 (PE6)
/STM32H7/PHY_RBIAS: R61.1, U24.24 (RBIAS)
/STM32H7/PHY_RXER: R52.1, U24.10 (RXER/PHYAD0)
/STM32H7/PHY_RXN: J21.6, U24.22 (RXN)
/STM32H7/PHY_RXP: J21.3, U24.23 (RXP)
/STM32H7/PHY_TXN: J21.2, U24.20 (TXN)
/STM32H7/PHY_TXP: J21.1, U24.21 (TXP)
/STM32H7/PHY_VDDCR: C133.1, U24.6 (VDDCR)
/STM32H7/PHY_XTAL1: C127.1, U24.5 (XTAL1/CLKIN), Y7.1
/STM32H7/PHY_XTAL2: C128.1, U24.4 (XTAL2), Y7.2
/STM32H7/PM0: U17.36 (G0), U23.111 (PM0)
/STM32H7/PM1: U17.35 (G1), U23.112 (PM1)
/STM32H7/PM2: U17.34 (G2), U23.113 (PM2)
/STM32H7/PM3: U17.33 (G3), U23.114 (PM3)
/STM32H7/PM5: U17.32 (G4), U23.118 (PM5)
/STM32H7/PM6: U17.31 (G5), U23.119 (PM6)
/STM32H7/PM8: U17.30 (G6), U23.121 (PM8)
/STM32H7/PM9: U17.29 (G7), U23.122 (PM9)
/STM32H7/PM13: U17.28 (G8), U23.127 (PM13)
/STM32H7/PO0: U5.20 (DIO_14), U23.64 (PO0)
/STM32H7/PO1: U5.21 (DIO_15), U23.44 (PO1)
/STM32H7/PO5: U17.2 (B8), U23.52 (PO5)
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

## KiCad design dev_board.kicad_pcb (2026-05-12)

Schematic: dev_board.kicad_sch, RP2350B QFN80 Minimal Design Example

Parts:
C3: 15p; C_0402_1005Metric; not fitted
C4: 15p; C_0402_1005Metric
C6, C7: 4.7u; C_0402_1005Metric_small_pads
C8, C11, C12, C13, C14, C15, C16, C17, C18, C20, C21, C22, C23, C24, C26, C27, C33, C38, C41, C42, C43, C44, C45, C49, C50, C51, C52, C54, C55, C56, C57, C59, C61, C63, C66, C67, C75, C77, C82, C85, C86, C87, C88, C90, C92, C93, C94: 100n; C_0402_1005Metric
C9, C10: 4.7u; C_0402_1005Metric
C19: 10u; C_0805_2012Metric
C25, C28, C30, C31, C34, C35, C46, C53, C58, C62, C68, C70, C72, C74, C76, C83, C84: 10u; C_0402_1005Metric
C29, C32, C36, C37, C60: 1u; C_0402_1005Metric
C39, C40, C81: 10n; C_0402_1005Metric
C47, C48, C69, C71, C73, C78, C79, C80: 2.2u; C_0402_1005Metric
C89: 1n; C_0402_1005Metric
C91: 22p; C_0402_1005Metric
C95: 47n; C_0402_1005Metric
C96, C97, C98: 100p; C_0402_1005Metric
FL1: 0900PC15A0036; Rohm_MLGA010V020A_LGA-10_2x2mm_P0.45mm_LayoutBorder2x3y
IC1: AD9609BCPZRL7-80; QFN50P500X500X100-33N; Manufacturer_Part_Number AD9609BCPZRL7-80; Mouser Part Number 584-AD9609BCPZR7-80
IC2: ENS161-BLGT_LGA9_T&R_1k5; ENS161BLGTLGA9TR1k5; Manufacturer_Part_Number ENS161-BLGT LGA9 T&R 1k5; Mouser Part Number 135-ENS161BGLTT&R1K5
IC3: ICM-42670-P; ICM42670P; Manufacturer_Part_Number ICM-42670-P; Mouser Part Number 410-ICM-42670-P
IC4: IWRL6432BDBAAMFR; BGA102C50P12X12_645X645X97; Manufacturer_Part_Number IWRL6432BDBAAMFR
IC5, IC10: MP4541GN-Z; SOIC127P600X170-9N; Manufacturer_Part_Number MP4541GN-Z; Mouser Part Number 946-MP4541GN-Z
IC6: THS8136IPHPR; QFP50P900X900X120-49N; Manufacturer_Part_Number THS8136IPHPR; Mouser Part Number 595-THS8136IPHPR
IC7, IC9: TPS40304ADRCR; Manufacturer_Part_Number TPS40304ADRCR; Mouser Part Number 595-TPS40304ADRCR
IC8: XCC1352R1F3RGZR; QFN50P700X700X100-49N-D; Manufacturer_Part_Number XCC1352R1F3RGZR
J2: Conn_02x26_Odd_Even; PinHeader_2x26_P2.54mm_Vertical
J4: SM03B-SRSS-TB; JST_SH_SM03B-SRSS-TB_1x03-1MP_P1.00mm_Horizontal
J5: STM32H7 GPIO/Fabric Breakout A; PinHeader_2x26_P2.54mm_Vertical
J6: STM32H7 GPIO/Fabric Breakout B; PinHeader_2x26_P2.54mm_Vertical
J9: HS/IWRL Fabric Breakout; PinHeader_2x26_P2.54mm_Vertical
J10: RJ45 / 8P8C LED; RJ45_Amphenol_RJMG1BD3B8K1ANR
J11: SMA_RF_LAUNCH; SMA_Amphenol_132134-10_Vertical
J12: RP2350 USB PROGRAM; USB_Micro-B_Amphenol_10103594-0001LF_Horizontal
J13, J14: DNP / not used; USB_Micro-B_Amphenol_10103594-0001LF_Horizontal
J15: IWRL USB PROGRAM; USB_Micro-B_Amphenol_10103594-0001LF_Horizontal
L1: 3.3u; L_pol_2016
L2: 10uH; L_0805_2012Metric
L3: 4.7uH; L_0805_2012Metric
MK1: IM69D120; Infineon_PG-LLGA-5-1
R2, R4, R6, R45, R46, R47, R48: 1k; R_0402_1005Metric
R3, R49, R50: 33; R_0402_1005Metric
R7, R8: 27; R_0402_1005Metric
R9, R10: 4.7k; R_0402_1005Metric
R11, R12, R13, R17, R18, R19, R22, R23, R26, R27, R28, R29: 10k; R_0402_1005Metric
R14: 330k; R_0402_1005Metric
R15, R16: 100k; R_0402_1005Metric
R24: 12.1k; R_0402_1005Metric
R25, R39, R40, R41: 2.2k; R_0402_1005Metric
R30: 0R; R_0402_1005Metric
R31: 3.8k; R_0402_1005Metric
R32, R33, R34, R42, R43, R44: 75; R_0402_1005Metric
R35, R36, R37, R38: 49.9; R_0402_1005Metric
SW1, SW2: SW_Push; SW_Push_1P1T_NO_Vertical_Wuerth_434133025816
TP1, TP2, TP3, TP4, TP5: TestPoint; TestPoint_Pad_3.0x3.0mm
U1: RP2350_80QFN; RP2350-QFN-80-1EP_10x10_P0.4mm_EP3.4x3.4mm_ThermalVias
U2: LPS22HH; ST_HLGA-10_2x2mm_P0.5mm_LayoutBorder3x2y
U3: STM32H750VBTx; LQFP-100_14x14mm_P0.5mm
U4: LAN8742A; VQFN-24-1EP_4x4mm_P0.5mm_EP2.5x2.5mm_ThermalVias
U5: PGA113; TSSOP-10_3x3mm_P0.5mm
U6: MCP6D11T-E/MS; MCP6D11T-E_MSOP-8_3x3mm_P0.65mm
U7: FT232RNL-TUBE; SSOP-28_5.3x10.2mm_P0.65mm
U8: XMSSJJ3G0PA-054; SOT-363_SC-70-6
Y1: ABM8-272-T3; Crystal_SMD_3225-4Pin_3.2x2.5mm
Y2: XRCMD48M000F1P2AR0; Crystal_SMD_2016-4Pin_2.0x1.6mm

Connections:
+3V3: C6.1, C12.1, C13.1, C14.1, C15.1, C16.1, C17.1, C18.1, C19.1, C20.1, C21.1, C22.1, C23.1, C24.1, C25.1, C26.1, C27.1, C28.1, C34.1, C35.1, C41.1, C42.1, C43.1, C44.1, C45.1, C46.1, C50.1, C51.1, C52.1, C62.1, C63.1, C80.1, C81.1, C82.1, C83.1, C84.1, C85.1, C86.1, C88.2, FL1.1 (ANT_2G4), IC2.4 (VDD), IC2.5 (VDDIO), IC3.5 (VDDIO), IC3.7 (FSYNC), IC3.8 (VDD), IC3.12 (AP_CS), IC6.40 (AVDD_2), IC6.44 (AVDD), IC8.13 (VDDS2), IC8.22 (VDDS3), IC8.34 (VDDS_DCDC), IC8.44 (VDDS), J2.2, J9.18, J9.40, J9.44, J9.52, L2.1, L3.2, MK1.5 (GND), R3.1, R9.1, R10.1, R13.1, R14.1, R17.2, R23.2, R25.2, R26.2, R28.2, R39.2, R40.2, R41.2, U1.5 (IOVDD), U1.15 (IOVDD), U1.24 (IOVDD), U1.29 (IOVDD), U1.41 (IOVDD), U1.50 (IOVDD), U1.59 (ADC_AVDD), U1.60 (IOVDD), U1.64 (VREG_VIN), U1.68 (USB_OTP_VDD), U1.69 (QSPI_IOVDD), U1.76 (IOVDD), U2.1 (Vdd_IO), U2.6 (~CS), U2.10 (VDD), U3.6 (VBAT), U3.11 (VDD), U3.20 (VREF+), U3.21 (VDDA), U3.27 (VDD), U3.50 (VDD), U3.75 (VDD), U3.100 (VDD), U4.1 (VDD2A), U4.9 (VDDIO), U4.19 (VDD1A), U5.1 (AV_{DD}), U5.10 (DV_{DD}), U6.3 (VDD), U8.3 (PORT2), U8.4 (VDD)
/ADC_AVDD_1V8: C55.1, C56.1, C57.1, C58.1, IC1.3 (AVDD_2), IC1.24 (AVDD_4), IC1.29 (AVDD_3), IC1.32 (AVDD)
/ADC_CLK_N: IC1.2 (CLK-), J5.18, U3.45 (PE15)
/ADC_CLK_P: IC1.1 (CLK+), J5.17, U3.44 (PE14)
/ADC_CSB: IC1.4 (CSB), J5.14, U3.41 (PE11)
/ADC_D0: IC1.11 ((LSB)D0), J5.3, U3.97 (PE0)
/ADC_D1: IC1.12 (D1), J5.4, U3.98 (PE1)
/ADC_D2: IC1.14 (D2), J5.5, U3.1 (PE2)
/ADC_D3: IC1.15 (D3), J5.6, U3.2 (PE3)
/ADC_D4: IC1.16 (D4), J5.7, U3.3 (PE4)
/ADC_D5: IC1.17 (D5), J5.8, U3.4 (PE5)
/ADC_D6: IC1.18 (D6), J5.9, U3.5 (PE6)
/ADC_D7: IC1.19 (D7), J5.10, U3.37 (PE7)
/ADC_D8: IC1.20 (D8), J5.11, U3.38 (PE8)
/ADC_D9: IC1.21 (D9(MSB)), J5.12, U3.39 (PE9)
/ADC_DCO: IC1.22 (DCO), J5.13, U3.40 (PE10)
/ADC_DRVDD: C59.1, IC1.13 (DRVD0)
/ADC_MODE_OR: IC1.23 (MODE/OR)
/ADC_RBIAS: IC1.28 (RBIAS), R29.1
/ADC_SCLK: IC1.5 (SCLK/DFS), J5.15, U3.42 (PE12)
/ADC_SDIO: IC1.6 (SDIO/PDWN), J5.16, U3.43 (PE13)
/ADC_SENSE: IC1.26 (SENSE), R30.1
/ADC_VCM: C61.1, IC1.27 (VCM), R46.1, U5.4 (V_{REF}), U6.2 (VOCM)
/ADC_VIN_N: C91.2, IC1.30 (VIN-), R49.2
/ADC_VIN_P: C91.1, IC1.31 (VIN+), R50.2
/ADC_VREF: C60.1, IC1.25 (VREF), R30.2
/CC_DCDC_SW: IC8.33 (DCDC_SW), L2.2
/CC_DCOUPL: C29.1, IC8.23 (DCOUPL)
/CC_DIO_3: IC8.8 (DIO_3), J6.31
/CC_DIO_4: IC8.9 (DIO_4), J6.32
/CC_DIO_5: IC8.10 (DIO_5), J6.33
/CC_DIO_7: IC3.9 (INT2), IC8.12 (DIO_7), J2.39, J6.35, U1.36 (GPIO28)
/CC_DIO_8: IC8.14 (DIO_8), J2.37, J6.36, U1.37 (GPIO29)
/CC_DIO_9: IC8.15 (DIO_9), J2.35, J6.37, U1.38 (GPIO30)
/CC_DIO_10: IC8.16 (DIO_10), J2.33, J6.38, U1.39 (GPIO31)
/CC_DIO_11: IC8.17 (DIO_11), J6.39
/CC_DIO_12: IC8.18 (DIO_12), J6.40
/CC_DIO_13: IC8.19 (DIO_13), J6.41
/CC_DIO_14: IC8.20 (DIO_14), J6.42
/CC_DIO_15: IC8.21 (DIO_15), J6.43
/CC_DIO_16: IC8.26 (DIO_16), J6.44
/CC_DIO_17: IC8.27 (DIO_17), J9.39
/CC_DIO_18: IC8.28 (DIO_18), J6.46
/CC_DIO_19: IC8.29 (DIO_19), J9.41
/CC_DIO_20: IC8.30 (DIO_20), J6.48
/CC_DIO_21: IC8.31 (DIO_21), J9.43
/CC_DIO_22: IC8.32 (DIO_22), J6.50
/CC_DIO_23: IC8.36 (DIO_23), J9.45
/CC_DIO_24: IC8.37 (DIO_24), J6.52
/CC_DIO_25: IC8.38 (DIO_25), J9.47
/CC_DIO_26: IC8.39 (DIO_26), J6.51
/CC_DIO_27: IC8.40 (DIO_27), J9.49
/CC_DIO_28: IC8.41 (DIO_28), J6.49
/CC_DIO_29: IC8.42 (DIO_29), J9.51
/CC_DIO_30: C97.2, FL1.4 (ANT_SUBG), IC8.43 (DIO_30), J6.47, U8.6 (CTL)
/CC_PROG_USB_D+: J14.3 (D+)
/CC_PROG_USB_D-: J14.2 (D-)
/CC_PROG_USB_VBUS: J14.4 (ID)
/CC_RESET_N: IC8.35 (RESET_N), J9.46, R13.2
/CC_RF_N_2G4: FL1.8 (RF_N_2G4), IC8.2 (RF_N_2_4GHZ)
/CC_RF_N_SUBG: FL1.6 (RF_N_SUBG), IC8.4 (RF_N_SUB_1GHZ)
/CC_RF_P_2G4: C98.2, FL1.9 (RF_P_2G4), IC8.1 (RF_P_2_4GHZ)
/CC_RF_P_SUBG: FL1.7 (RF_P_SUBG), IC8.3 (RF_P_SUB_1GHZ)
/CC_TCKC: IC8.25 (JTAG_TCKC), J6.45
/CC_TMSC: IC8.24 (JTAG_TMSC), J9.50
/CC_VDDR: C30.1, IC8.45 (VDDR), IC8.48 (VDDR_RF)
/CC_X32K_Q1: IC8.6 (X32K_Q1)
/CC_X32K_Q2: IC8.7 (X32K_Q2)
/CC_X48M_N: IC8.46 (X48M_N), Y2.3
/CC_X48M_P: IC8.47 (X48M_P), Y2.1
/DAC_B0: IC6.10 (B0), J5.19, U3.81 (PD0)
/DAC_B1: IC6.9 (B1), J5.20, U3.82 (PD1)
/DAC_B2: IC6.8 (B2), J5.21, U3.83 (PD2)
/DAC_B3: IC6.7 (B3), J5.22, U3.84 (PD3)
/DAC_B4: IC6.6 (B4), J5.23, U3.85 (PD4)
/DAC_B5: IC6.5 (B5), J5.24, U3.86 (PD5)
/DAC_B6: IC6.4 (B6), J5.25, U3.87 (PD6)
/DAC_B7: IC6.3 (B7), J5.26, U3.88 (PD7)
/DAC_B8: IC6.2 (B8), J5.27, U3.55 (PD8)
/DAC_B9: IC6.1 (B9), J5.28, U3.56 (PD9)
/DAC_BLANK_N: IC6.23 (~BLANK), J6.24, R40.1, U3.66 (PC9)
/DAC_CLK: IC6.26 (CLK), J6.21, R39.1, U3.63 (PC6)
/DAC_COMP: C66.1, IC6.39 (COMP)
/DAC_FSADJ: IC6.38 (FSADJ), R31.1
/DAC_G0: IC6.36 (G0), J5.29, U3.57 (PD10)
/DAC_G1: IC6.35 (G1), J5.30, U3.58 (PD11)
/DAC_G2: IC6.34 (G2), J5.31, U3.59 (PD12)
/DAC_G3: IC6.33 (G3), J5.32, U3.60 (PD13)
/DAC_G4: IC6.32 (G4), J5.33, U3.61 (PD14)
/DAC_G5: IC6.31 (G5), J5.34, U3.62 (PD15)
/DAC_G6: IC6.30 (G6), J5.51, U3.34 (PB0)
/DAC_G7: IC6.29 (G7), J5.52, U3.35 (PB1)
/DAC_G8: IC6.28 (G8), J6.1, U3.36 (PB2)
/DAC_G9: IC6.27 (G9), J6.2, U3.89 (PB3)
/DAC_M1: IC6.47 (M1), J6.25, U3.78 (PC10)
/DAC_M2: IC6.48 (M2), J6.26, U3.79 (PC11)
/DAC_R0: IC6.13 (R0), J6.3, U3.90 (PB4)
/DAC_R1: IC6.14 (R1), J6.4, U3.91 (PB5)
/DAC_R2: IC6.15 (R2), J6.7, U3.95 (PB8)
/DAC_R3: IC6.16 (R3), J6.8, U3.96 (PB9)
/DAC_R4: IC6.17 (R4), J5.2, U3.13 (PH1)
/DAC_R5: IC6.18 (R5), J6.13, U3.53 (PB14)
/DAC_R6: IC6.19 (R6), J6.14, U3.54 (PB15)
/DAC_R7: IC6.20 (R7), J6.15, U3.15 (PC0)
/DAC_R8: IC6.21 (R8), J6.17, U3.17 (PC2_C)
/DAC_R9: IC6.22 (R9), J6.10, U3.47 (PB11)
/DAC_SYNC_N: IC6.24 (~SYNC), J6.23, R41.1, U3.65 (PC8)
/DAC_SYNC_T: IC6.25 (SYNC-T), J6.22, U3.64 (PC7)
/DAC_VREF: C67.1, IC6.37 (VREF)
/ENS_ADDR: IC2.3 (MISO_/_ADDR), R11.1
/ETH_CRS_DV: J5.42, U3.31 (PA7), U4.11 (CRS_DV/MODE2)
/ETH_CT: C87.1, R35.2, R36.2, R37.2, R38.2
/ETH_CT1: J10.5 (CT2)
/ETH_CT2: J10.4 (CT1)
/ETH_MDC: J6.16, U3.16 (PC1), U4.13 (MDC)
/ETH_MDIO: J5.37, R25.1, U3.24 (PA2), U4.12 (MDIO)
/ETH_REFCLK_INT: J5.36, U3.23 (PA1), U4.14 (~INT/REFCLKO)
/ETH_RST_N: R26.1, U4.15 (~RST)
/ETH_RXD0: J6.19, U3.32 (PC4), U4.8 (RXD0/MODE0)
/ETH_RXD1: J6.20, U3.33 (PC5), U4.7 (RXD1/MODE1)
/ETH_RXER: U4.10 (RXER/PHYAD0)
/ETH_RX_N: J10.6 (RD-), R38.1, U4.22 (RXN)
/ETH_RX_P: J10.3 (RD+), R37.1, U4.23 (RXP)
/ETH_TXD0: J6.11, U3.51 (PB12), U4.17 (TXD0)
/ETH_TXD1: J6.12, U3.52 (PB13), U4.18 (TXD1)
/ETH_TXEN: J6.9, U3.46 (PB10), U4.16 (TXEN)
/ETH_TX_N: J10.2 (TD-), R36.1, U4.20 (TXN)
/ETH_TX_P: J10.1 (TD+), R35.1, U4.21 (TXP)
/GPIO0: J2.4, U1.77 (GPIO0)
/GPIO1: J2.6, U1.78 (GPIO1)
/GPIO2: J2.8, MK1.3 (CLOCK), U1.79 (GPIO2)
/GPIO3: J2.10, MK1.4 (SELECT), U1.80 (GPIO3)
/GPIO4: J2.12, MK1.1 (DATA), U1.1 (GPIO4)
/GPIO5: J2.14, U1.2 (GPIO5)
/GPIO7: IC3.4 (INT1_/_INT), J2.18, U1.4 (GPIO7)
/GPIO8: J2.20, U1.6 (GPIO8)
/GPIO9: J2.22, U1.7 (GPIO9), U2.7 (INT_DRDY)
/GPIO10: J2.24, U1.8 (GPIO10), U5.7 (SCLK)
/GPIO11: J2.26, U1.9 (GPIO11), U5.8 (DIO)
/GPIO12: J2.28, U1.11 (GPIO12), U5.9 (~CS)
/GPIO13: J2.30, U1.12 (GPIO13), U6.7 (~PD)
/GPIO14: J2.32, U1.13 (GPIO14)
/GPIO15: J2.34, U1.14 (GPIO15)
/GPIO16: J2.36, J5.35, J9.1, U1.16 (GPIO16), U3.22 (PA0)
/GPIO17: J2.38, J5.38, J9.2, U1.17 (GPIO17), U3.25 (PA3)
/GPIO18: J2.40, J5.39, J9.3, U1.18 (GPIO18), U3.28 (PA4)
/GPIO19: J2.42, J5.40, J9.4, U1.19 (GPIO19), U3.29 (PA5)
/GPIO20: J2.44, J5.41, J9.5, U1.20 (GPIO20), U3.30 (PA6)
/GPIO21: J2.46, J5.43, J9.6, U1.21 (GPIO21), U3.67 (PA8)
/GPIO22: J2.48, J5.44, J9.7, U1.22 (GPIO22), U3.68 (PA9)
/GPIO23: J2.50, J5.45, J9.8, U1.23 (GPIO23), U3.69 (PA10)
/GPIO24: J2.52, J5.46, J9.9, U1.25 (GPIO24), U3.70 (PA11)
/GPIO25: J2.51, J5.47, J9.10, U1.26 (GPIO25), U3.71 (PA12)
/GPIO26: J2.49, U1.27 (GPIO26)
/GPIO32: IC4.A10 (QSPI_CS), J2.31, J5.50, J9.11, U1.40 (GPIO32), U3.77 (PA15)
/GPIO33: IC4.A11 (QSPI_CLK), J2.29, J6.27, J9.12, U1.42 (GPIO33), U3.80 (PC12)
/GPIO34: IC4.B11 (QSPI[0]), J2.27, J6.28, J9.13, U1.43 (GPIO34), U3.7 (PC13)
/GPIO35: IC4.B8 (QSPI[1]), J2.25, J6.29, J9.14, U1.44 (GPIO35), U3.8 (PC14)
/GPIO36: IC4.B10 (QSPI[2]), J2.23, J6.30, J9.15, U1.45 (GPIO36), U3.9 (PC15)
/GPIO37: IC4.B9 (QSPI[3]), J2.21, J5.1, J9.16, U1.46 (GPIO37)
/GPIO38: J2.19, U1.47 (GPIO38)
/GPIO39: J2.17, U1.48 (GPIO39)
/GPIO40_ADC0: J2.15, U1.49 (GPIO40_ADC0)
/GPIO41_ADC1: J2.13, U1.52 (GPIO41_ADC1)
/GPIO42_ADC2: J2.11, U1.53 (GPIO42_ADC2)
/GPIO43_ADC3: J2.9, U1.54 (GPIO43_ADC3)
/GPIO44_ADC4: J2.7, U1.55 (GPIO44_ADC4)
/GPIO45_ADC5: J2.5, U1.56 (GPIO45_ADC5)
/GPIO46_ADC6: J2.3, U1.57 (GPIO46_ADC6)
/GPIO47_ADC7: J2.1, U1.58 (GPIO47_ADC7)
/IMU_AD0: IC3.1 (AP_SDO_/_AP_AD0)
/IWR_CLKM: IC4.B1 (CLKM)
/IWR_CLKP: IC4.D1 (CLKP)
/IWR_FTDI_3V3OUT: C94.1, U7.17 (3V3OUT)
/IWR_GPADC1: IC4.M6 (GPADC1), J9.36
/IWR_GPADC2: IC4.L6 (GPADC2), J9.37
/IWR_GPIO_2: IC4.H10 (GPIO_2), J9.32
/IWR_GPIO_5: IC4.J10 (GPIO_5), J9.33
/IWR_HOST_CLK_REQ: IC4.M10 (HOST_CLK__REQ), J9.34
/IWR_NERROR: IC4.K11 (NERROR__OUT), J9.31
/IWR_NRST: IC4.L10 (NRESET), J9.26
/IWR_OSC_CLK_OUT: IC4.A7 (OSC_CLK__OUT)
/IWR_PMIC_CLKOUT: IC4.H11 (PMIC__CLKOUT), J9.35
/IWR_PROG_USB_D+: J15.3 (D+), U7.15 (USBD+)
/IWR_PROG_USB_D-: J15.2 (D-), U7.16 (USBD-)
/IWR_RX1: IC4.K1 (RX1)
/IWR_RX2: IC4.H1 (RX2)
/IWR_RX3: IC4.F1 (RX3)
/IWR_SPI_CLK: IC4.D10 (SPIA_CLK), J9.21
/IWR_SPI_CS_N: IC4.D11 (SPIA_CS0__N), J9.22
/IWR_SPI_MISO: IC4.C11 (SPIA_MISO), J9.20
/IWR_SPI_MOSI: IC4.B12 (SPIA_MOSI), J9.19
/IWR_TCK: IC4.C12 (TCK), J9.27
/IWR_TDI: IC4.G11 (TDI), J9.29
/IWR_TDO: IC4.E11 (TDO), J9.30
/IWR_TMS: IC4.E12 (TMS), J9.28
/IWR_TX1: IC4.A3 (TX1)
/IWR_TX2: IC4.A5 (TX2)
/IWR_UART_RTS: IC4.L11 (UARTA_RTS), J9.25
/IWR_UART_RX: IC4.J11 (UARTA_RX), J9.24, U7.1 (TXD)
/IWR_UART_TX: IC4.L12 (UARTA_TX), J9.23, U7.5 (RXD)
/IWR_USB_VBUS: C92.1, J15.1 (VBUS), U7.20 (VCC)
/IWR_VDDA_1V0RF: C72.1, C73.1, IC4.L3 (VDDA_10RF_1), IC4.M3 (VDDA_10RF_2)
/IWR_VDDA_1V2RF: C68.1, C69.1, IC4.L4 (VDDA_12RF_1), IC4.M4 (VDDA_12RF_2)
/IWR_VDDA_1V8: C76.1, C77.1, IC4.F3 (VDDA__18VCO), IC4.J5 (VIN_18PM), IC4.L5 (VDDA_18BB_1), IC4.M5 (VDDA_18BB_2)
/IWR_VDD_1V2: IC4.C9 (VDD_1), IC4.G7 (VDD_2), IC4.G8 (VDD_3), IC4.G9 (VDD_4), IC4.H8 (VDD_5), IC4.K7 (VDD_6)
/IWR_VDD_SRAM: C70.1, C71.1, IC4.M7 (VDD_SRAM)
/IWR_VIO_1V8: C74.1, C75.1, C93.1, IC4.C6 (VIOIN__18CLK), IC4.C8 (VIOIN_18_1), IC4.G12 (VIOIN_1), IC4.K12 (VIOIN_18_2), IC4.L8 (VIOIN_18_3), IC4.M8 (VIOIN_18_4), IC4.M11 (VIOIN_2), U7.4 (VCCIO), U7.19 (~RESET)
/IWR_VOUT_1V4_APLL: C79.1, IC4.G5 (VOUT__14APLL)
/IWR_VOUT_1V4_SYNTH: C78.1, IC4.D3 (VOUT__14SYNTH)
/IWR_VPP: IC4.A8 (VPP)
/LPS_SA0: R12.1, U2.5 (SA0)
/MP_BST: C33.1, IC5.5 (BST), IC10.5 (BST)
/MP_EN: IC5.1 (EN), IC10.1 (EN), R16.2
/MP_FB: IC5.4 (FB), IC10.4 (FB), R14.2, R15.1
/MP_FREQ: IC5.3 (FREQ), IC10.3 (FREQ)
/MP_SW: C33.2, IC5.6 (SW), IC10.6 (SW), L3.1
/MP_VCC: C32.1, IC5.2 (VCC), IC10.2 (VCC)
/PHY_LED1_REGOFF: J10.9 (LED1A), R27.1, U4.3 (LED1/REGOFF)
/PHY_LED2_INTSEL: J10.11 (LED2A), R28.1, U4.2 (LED2/~INTSEL)
/PHY_RBIAS: R24.1, U4.24 (RBIAS)
/PHY_VDDCR: C53.1, C54.1, U4.6 (VDDCR)
/PHY_XTAL1: U4.5 (XTAL1/CLKIN)
/PHY_XTAL2: U4.4 (XTAL2)
/QSPI_SCLK: U1.71 (QSPI_SCLK)
/QSPI_SD0: U1.72 (QSPI_SD0)
/QSPI_SD1: U1.74 (QSPI_SD1)
/QSPI_SD2: U1.73 (QSPI_SD2)
/QSPI_SD3: U1.70 (QSPI_SD3)
/QSPI_SS: R6.1, U1.75 (QSPI_SS)
/RUN: J2.41, SW2.2, U1.35 (RUN)
/SCOPE_AUX_IN: TP2.1, U5.2 (CH1)
/SCOPE_IN: TP1.1, U5.3 (CH0/V_{CAL})
/SENS_I2C_SCL: IC2.2 (SCLK_/_SCL), IC3.13 (AP_SCL_/_AP_SCLK), J6.5, R9.2, U2.2 (SCL), U3.92 (PB6)
/SENS_I2C_SDA: IC2.1 (MOSI_/_SDA), IC3.14 (AP_SDA_/_AP_SDIO_/_AP_SDI), J6.6, R10.2, U2.4 (SDA), U3.93 (PB7)
/STM_NRST: C49.1, R23.1, U3.14 (NRST)
/STM_PC3_C: J6.18, U3.18 (PC3_C)
/STM_SWCLK: J5.49, U3.76 (PA14)
/STM_SWDIO: J5.48, U3.72 (PA13)
/STM_USB_FS_DM: J13.2 (D-)
/STM_USB_FS_DP: J13.3 (D+)
/STM_USB_VBUS: J13.1 (VBUS)
/STM_VCAP1: C47.1, U3.48 (VCAP)
/STM_VCAP2: C48.1, U3.73 (VCAP)
/STM_VCAP_A: U3.12 (PH0)
/TPS_BOOT: C38.1, IC7.6 (BOOT), IC9.6 (BOOT)
/TPS_BP: C37.1, IC7.10 (BP), IC9.10 (BP)
/TPS_COMP: C40.1, IC7.4 (COMP), IC9.4 (COMP), R22.1
/TPS_ENSS: C39.1, IC7.2 (EN/SS), IC9.2 (EN/SS)
/TPS_FB: IC7.5 (FB), IC9.5 (FB), R18.2, R19.1, R22.2
/TPS_HDRV: IC7.7 (HDRV), IC9.7 (HDRV)
/TPS_LDRV_OC: IC7.9 (LDRV/_OC), IC9.9 (LDRV/_OC)
/TPS_PGOOD: IC7.3 (PGOOD), IC9.3 (PGOOD), R17.1
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

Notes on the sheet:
DAC island: PD/PB/PC/PH1 assigned to THS8136 RGB bus/timing; fabric is kept off these pins.
CC1352 island: recommended decoupling, DCDC and crystal nets
Schematic completion notes
Review before layout: RF matching, ADC analog front-end, Ethernet magnetics, and regulator loop values are topology-dependent.
USB programming ports: J12 RP2350 native USB; J13 STM32 DFU optional via R52/R53; J14 CC1352 programmer bridge USB input, DNP in this revision; J15 IWRL USB-UART at 1.8V I/O.
RJ45 Ethernet island: cable connector / MagJack-side breakout for LAN8742A pairs and LEDs.
CC1352: DCOUPL/VDDR/DCDC support is shown; RF balun/matching network should follow the selected reference design.
Extra explicit passives from datasheet application/BOM sections
RP2350 scope control: GPIO10=PGA SCLK, GPIO11=PGA SDIO, GPIO12=PGA CS_N, GPIO13=MCP6D11 PD_N
IOs
ADC island: AD9609 AVDD/DRVDD/VREF/VCM/RBIAS support
12MHz Crystal
ADC and THS8136 analog support below boundary
CC1352 island: DCOUPL/VDDR/DCDC/crystal support
Power
Codex generated recommended support components - cross-boundary data uses labels only
No generated data wire crosses the horizontal user boundary; shared signals use local net labels.
ADC island: PE0-PE15 assigned to AD9609 data/control/clock nets
Electrical net names preserve existing RP2350 GPIO labels; role notes map those GPIOs to HS_Dx/QSPI functions.
STM32H750 and LAN8742A support below boundary
Ethernet island: LAN8742A RBIAS, VDDCR, magnetics termination
Keep exact/application-specific values for PHY RBIAS 12.1k, Ethernet 49.9R, video 75R, DAC FSADJ 3.8k.
Intentional crossings: GPIO16-GPIO25 are RP-to-STM parallel fabric; GPIO32-GPIO37 are shared RP/STM/IWR QSPI.
STM32/LAN8742A: RMII nets are label-connected below the boundary; unused STM32 GPIOs are intentionally left for expansion.
RF SMA launch: stuff after selected CC1352 balun/matching network; keep 50 ohm controlled impedance.
Place 1k FDA gain/feedback resistors tight to MCP6D11 pins; place 33R/22p ADC filter tight to AD9609 VIN pins.
Buck regulator recommended bootstrap, feedback, soft-start and compensation parts
Boot/strap pins are tied by labels and pull resistors; change these only with firmware/boot-mode review.
Island plan: PE=ADC, PD/PB/PC/PH1=DAC, PA+PC12-15+PH0=fabric, Ethernet keeps existing PA/PB/PC pins.
J9 combines the fabric and IWRL breakout: GPIO32-37 are the IWRL high-speed QSPI bus; lower pins expose IWRL SPIA/UART/JTAG/control.
DAC island: THS8136 DVDD/AVDD/VREF/FSADJ/output loads
Sensor I2C pulls and local decoupling
JST Debug Connector
IWRL island: LDO-output 10u + 2.2u capacitors
IWRL island: LDO-output and supply decoupling below boundary
Power island: buck bootstrap, comp, feedback, SS and FET gate resistors
Make sure R7 and R8 are close to RP2350
IWRL6432: LDO-output caps follow datasheet typical 10u + 2.2u groups; RF pins still need layout/reference-design matching.
RP-to-STM parallel fabric: GPIO16-23=HS_D0-D7, GPIO24=HS_CLK, GPIO25=HS_FRAME
I2C sensor bus: ENS161, ICM-42670-P, and LPS22HH share SENS_I2C_SCL/SDA with one pullup pair; strap ENS_ADDR, IMU_AD0, and LPS_SA0 intentionally; IC2 INTN -> GPIO27 and IC3 INT2 -> GPIO28.

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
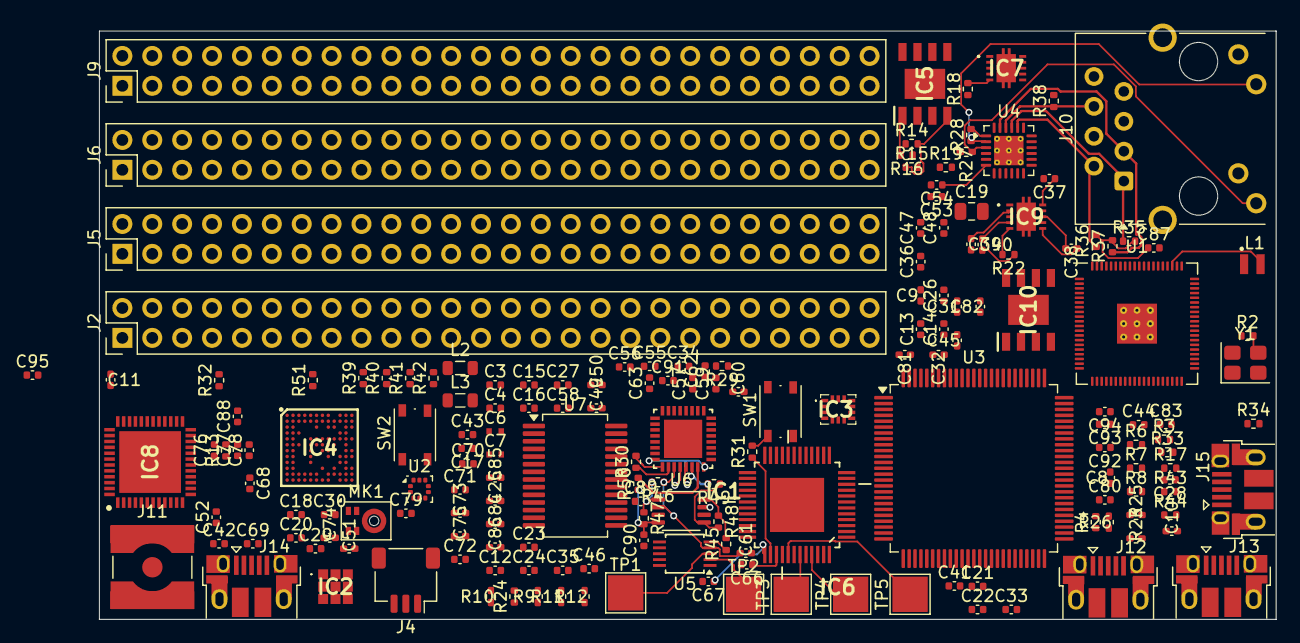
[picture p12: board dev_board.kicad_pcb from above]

Board: 4 copper layers, 100.0 x 50.0 mm, 177 parts (0 on the bottom side), 243 nets.

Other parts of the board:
R51: 0R/DNP; R_0402_1005Metric

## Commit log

2026-04-18 demarcation of boundaries, ethenret PHY
    [dev_board.kicad_sch, dev_board.sch]
2026-05-02 more pcb chanegs, ADC fixes
    [dev_board.kicad_pcb, dev_board.kicad_sch]
2026-05-02 more pcb chanegs, placements
    [dev_board.kicad_pcb, dev_board.kicad_sch]
2026-05-03 more fixes
    [dev_board.kicad_pcb, dev_board.kicad_sch]
2026-05-12 more pcb stuff
    [dev_board.kicad_pcb, dev_board.kicad_sch]
2026-07-19 Finalize production PCB handoff
    [IWRL6432BDBAAMFR_breakout.kicad_sch, RP2350B_minimal_hier.kicad_sch, SHA256SUMS.csv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]
2026-07-19 Select L1 = KYOCERA AVX LMLP07C7M1R0DTAS; add KiCad CI branch protection
    - Add proper power-inductor footprint L_Kyocera_LMLP07C7_7.0x6.9mm
    (2.4x6.0 mm pads, 4.6 mm centre-to-centre) to replace the 0603
    L_TODO_SELECT_1uH_15Aplus placeholder for the MIC28516 buck output
    inductor (net /Power/SW -> +3V3). Land pattern derived from the LMLP07
    series; flagged in descr for datasheet verification before fab.
    - Record the part in power.kicad_sch L1 (Value, Footprint, Datasheet,
    Manufacturer, MPN) and in the production BOM.
    - Add .github/workflows/kicad-checks.yml: headless KiCad 9 DRC gate on the
    production board (required) plus informational working-board DRC and
    schematic ERC, on pul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
    [dev-real-production-bom.csv, power.kicad_sch]
2026-07-19 Correct LMLP07C7 land pattern to datasheet-verified dimensions
    Replace the estimate-based footprint with one built from the actual
    LMLP07C7 dimensional table in datasheets.kyocera-avx.com/LMLPD.pdf
    (Style D, case 07C7): body 7.3x6.6mm (was estimated 7.0x6.9mm), pads
    2.95x3.5mm at 5.45mm pitch (was estimated 2.4x6.0mm at 5.45mm pitch).
    Also confirms LMLP07C7M1R0DTAS electricals: 1uH +/-20%, DCR 6.1/6.5
    mOhm typ/max, IDC 15A typ, Isat 20A typ - matching the values already
    used in the schematic/BOM.
    Claude-Session: https://claude.ai/code/session_0186Z8rzxmfg6xURJrUFb6p5
    [dev-real-production-bom.csv, power.kicad_sch]
2026-07-19 Widen L1-area SW/+3V3 traces for 15A current capacity
    Per-segment clearance-checked widening (0.2-0.4mm, up from 0.1-0.2mm)
    of the /Power/SW and +3V3 track segments in the L1 reroute area,
    matching the board's existing convention for local high-current power
    hops. Verified via real kicad-cli DRC on both boards: 0 unconnected
    items, no new violations (production: 1 pre-existing courtyard
    overlap remains; working copy: unchanged 4 violations/6 unconnected,
    all pre-existing and unrelated to L1).
    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
    [dev-real-production.kicad_pcb, dev-real.kicad_pcb]
2026-07-19 Fix C5/COUT2 courtyard overlap and widen remaining thin high-current traces
    C5 relocated from (68.5,59.5) to (67.7,57.75)mm to clear its courtyard
    overlap with COUT2 (COUT2 itself can't move - the channel to L1 is too
    narrow in any orientation). Its two local nets (RIPPLE_INJ, FB) were
    rerouted to the new pad positions, routing FB around an EXTVDD track
    that blocked the direct path. Six duplicate FB stub segments left over
    from earlier fix attempts this session were deduped in the process.
    Production board DRC is now fully clean: 0 violations, 0 unconnected.
    Also widened 5 thin (0.15mm) inner-layer segments on
    /IWRL6432BD/USB_VBUS (found via a whole-board high-current trace
    audit) to 0.2-0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
    [dev-real-production.kicad_pcb, dev-real.kicad_pcb]
2026-07-20 Fix malformed board outline on dev-real.kicad_pcb
    The working copy's Edge.Cuts outline had a gap/self-intersection near
    the top-right corner (segments not meeting: right edge stopped at
    y=104.64, top edge ran y=103.43 instead of closing the rectangle),
    causing 3 invalid_outline DRC violations. Replaced with the same
    clean (0,0)-(105,0)-(105,105)-(0,105) rectangle already used on the
    production board. No components sit in the affected corner region.
    DRC: 0 violations (down from 3), 6 unconnected items remain (known
    pre-existing BGA-area gaps, being fixed separately).
    Claude-Session: https://claude.ai/code/session_0186Z8rzxmfg6xURJrUFb6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
    [dev-real.kicad_pcb]
2026-07-20 Fix all remaining unconnected items on dev-real.kicad_pcb
    Resolved the last 6 connectivity gaps around the U13 radar BGA corner
    (GND ball M12, an In2/GND stub near (56.9,16.0), C34 pad 1, U21 pad
    26, a split GND plane island on In1, and an NRESET In1<->F gap), each
    fixed and verified against real kicad-cli DRC individually. Most
    needed via-in-pad connections plus small local shoves of neighboring
    nets (FT_RXD, GPIO_4) that were routed directly under the affected
    pads, since escape-track congestion in that corner defeats the
    default interactive shove router.
    Both boards are now fully clean: dev-real.kicad_pcb and
    dev-real-production.kicad_pcb are each at 0 DRC violations, 0
    unconnected items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
    [dev-real.kicad_pcb]
2026-07-20 Fix CI: drop unsupported pipefail option breaking the required DRC gate
    The KiCad 9 docker image runs GitHub Actions steps under sh (dash),
    which doesn't support bash's -o pipefail. That crashed the DRC step
    before kicad-cli even ran, so the required production-board gate
    failed on every run regardless of the board's actual DRC state (which
    has been 0 violations / 0 unconnected since the last fix). Dropping
    pipefail (there's no pipe in this script to protect) fixes it.
    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
2026-08-23 release: finalize dev-board fabrication package
    - Remove two orphaned unannotated symbols (FB?, L?) from the XCC1352 sheet that crashed KiCad 9.0.7 ERC (access violation in eeschema.dll); they had no connections and no footprint counterparts on either PCB.
    - Both dev-real.kicad_pcb and dev-real-production.kicad_pcb: 0 DRC errors, 0 unconnected items.
    - Generate complete release/final/ with Gerbers, Excellon drills + maps, BOM, positions, schematic PDF, ERC/DRC reports, RELEASE_NOTES, SHA256 manifest.
    /AD9609/SCOPE_BIAS remains the single user-accepted unresolved issue (no DC source; documented in RELEASE_NOTES).
    [SHA256SUMS.csv, XCC1352R1F3RGZR_breakout.kicad_sch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]
2026-08-24 release: regenerate SHA256 manifest from checked-out text file bytes
    Git autocrlf normalized line endings for 3 text files on commit, so their hashes in the previous manifest did not match a fresh clone. Manifest now hashes exactly what a user downloads.
    [SHA256SUMS.csv]
2026-08-24 fix: ETH TX differential pair skew matched to 0.000mm
    Added a 5.274mm length-matching extension to /STM32H7/PHY_TXN on Top Layer so both legs of the Ethernet TX pair are now exactly equal length. DRC verified: 0 errors, 0 unconnected items.
    Regenerated all production Gerbers, drill files, positions and reports from the updated PCB.
    [SHA256SUMS.csv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]
2026-09-08 docs: document current routing and signal integrity status
    [SHA256SUMS.csv]
2026-09-08 route: save manual connector pair tuning candidate
    [dev-real-production.kicad_pcb]
2026-09-08 route: update manual pair tuning candidate
    [dev-real-production.kicad_pcb]
2026-09-08 route: refine STM32 USB pair matching
    [dev-real-production.kicad_pcb]
2026-09-08 pcb: clean basic DRC findings and document remaining work
    [dev-real-production.kicad_pcb]
2026-09-08 pcb: remove dangling copper and refill zones
    [dev-real-production.kicad_pcb]
